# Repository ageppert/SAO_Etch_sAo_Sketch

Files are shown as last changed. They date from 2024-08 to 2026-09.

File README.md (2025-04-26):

# Etch sAo Sketch

The perfect pairing of an OLED Display, analog potentiometers, and a 3-axis accelerometer!

This is the primary repository for all things relevant to the Etch sAo Sketch.

Learn more about this project at: https://hackaday.io/project/197581-etch-sao-sketch

If you use the Arduino Demo code make sure it is configured for your hardware version (HWV) of the Etch sAo Sketch.

IMPORTANT ERRATA APPLIES TO ALL VERSIONS:

There is too much combined pull-up resistance with this board, the OLED board, the Hackaday Badge, and the Pico. This inhibits some I2C hardware implementations from working with the OLED display.

SOLUTION A: Firmware workaround is to use software I2C. See: https://github.com/ageppert/SAO_Etch_sAo_Sketch/pull/1

SOLUTION B: Hardware mods to remove interfering components. See: https://github.com/ageppert/SAO_Etch_sAo_Sketch/issues/8

-------------

# V1.3 - OLED VERSION - Hackaday Europe 2025 Elecrow version

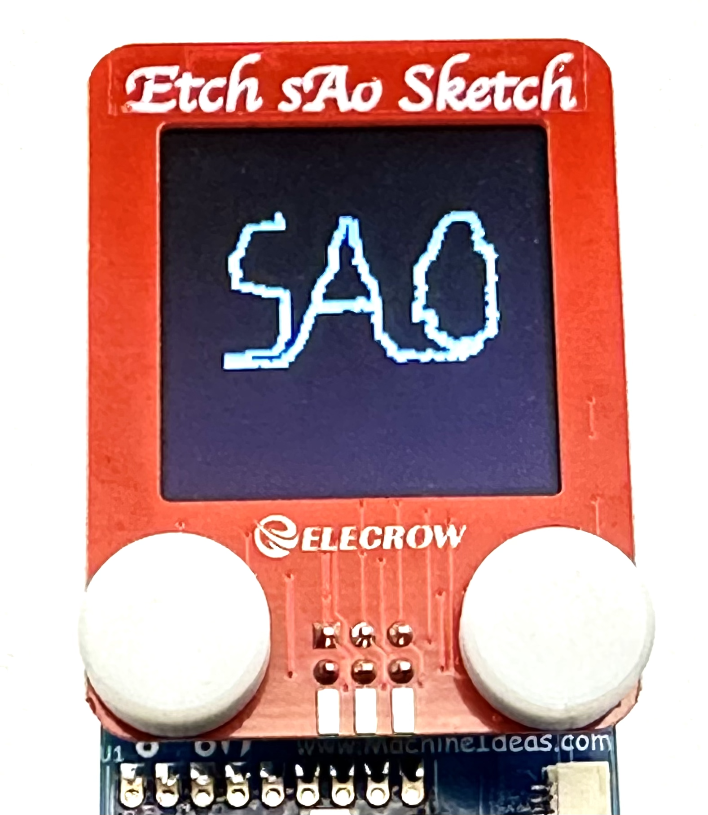
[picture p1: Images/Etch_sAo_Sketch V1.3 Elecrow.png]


This version was manufactured for Hackaday Europe 2025 by Elecrow and includes the Elecrow logo on the PCB below the screen. The files have been copied into this repository for easy reference, although it was in a more generic "SAO Sketch" repo for production. Hopefully you got a sticker from one of us to upgrade your SAO to "Etch sAo Sketch" when we were together in Berlin!

V1.3.1 FIXES: Removed I2C Pull-up Resistors R1/2 from the board.

-------------

# V1.2 - OLED VERSION - NOT BUILT

This version was an un-fabricated step in the development for Hackaday Europe 2025 with a separate repository located here: https://github.com/ageppert/SAO_Sketch. This version builds on V1.1 with some clean-up in the schematic and layout.

-------------

# V1.1 - OLED VERSION - Small batch to sell on Tindie

Refinements include:
1) Enable full range of the analog pots via the accelerometer's [reduced range] ADC inputs, with the option to still use analog signals on GPIO 1 and 2.
2) Use a taller male SAO header for easier connection to the main (red) PCBA.
3) Tweak alignment hole size/position for the alignment spheres and OLED position.

V1.1.1 FIXES: Removed I2C Pull-up Resistors R1/2 from the board.

Otherwise, it looks and functions just like V1.0.

-------------

# V1.0 - OLED VERSION - Shared at Hackaday Supercon.8 in 2024 and on Tindie

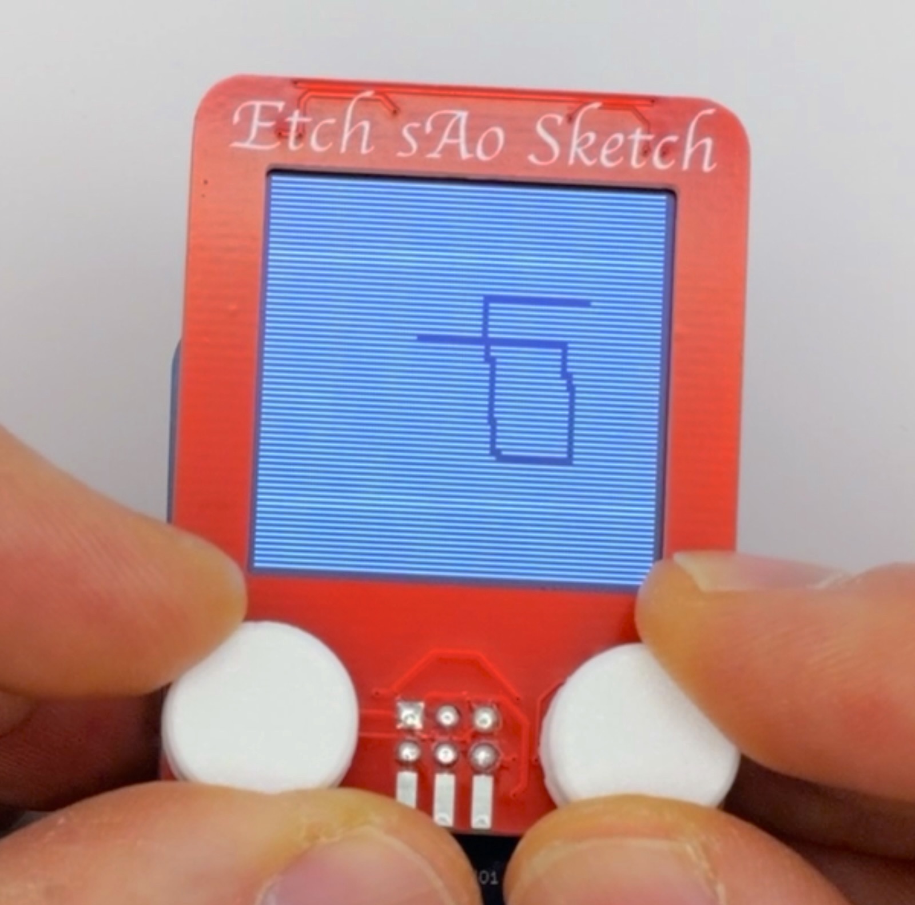
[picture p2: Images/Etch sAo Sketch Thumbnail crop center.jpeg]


This version was shared at Hackaday Supercon.8 2024. It is available for purchase here: https://www.tindie.com/products/36383/

V1.0.1 FIXES: Removed I2C Pull-up Resistors R30/31 from the board.

V1.0 ERRATA: The full travel of the analog pots is only available through [analog] GPIO1&2 of the SAO port, and this works best when connected to analog pins of an MCU. My SAO DEMO CONTROLLER is a good host to use the V1.0 Etch sAo Sketch with. A reduced range of travel is available through the accelerometer ADC inputs via I2C. The included SAO Header pins need to be pushed back into the header body 1 mm so they extend far enough to be connected to the red PCBA after the OLED PCBA is stacked on the bottom.

The SAO DEMO CONTROLLER is available for purchase here: https://www.tindie.com/products/36033/

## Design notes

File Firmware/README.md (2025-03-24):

# Etch_sAo_Sketch Firmware Examples

The Etch sAo Sketch requires a microcontroller with an I2C bus to run. This folder contains a few examples.

"Etch_sAo_Sketch_V1.0_RP2040_W_Arduino_Demo" is designed to work with the SAO Demo Controller, or any RP2040-based board. It provides the full drawing functionality for the V1 Etch sAo Sketch.

"Etch_sAo_Sketch_V1.1_RP2040_W_Arduino_Demo" is refined for the V1.1 Etch sAo Sketch which has resistors added in series with the potentiometers to allow full travel of the knobs to map to the full screen. It's a quality of life improvement.

"OLED_ssd1327_test" is Arduino sample code to activate the OLED screen.

"Supercon.8_Badge_Micropython" are the files needed to run the Etch sAo Sketch with the 2024 Supercon.8 and Hackaday Europe 2025 Badges using Micropython. Etch-sAo-Sketch must be plugged into the port marked "6" when the badge boots up. If used, the petal and touchwheel SAOs goes in "1", "2" or "3".

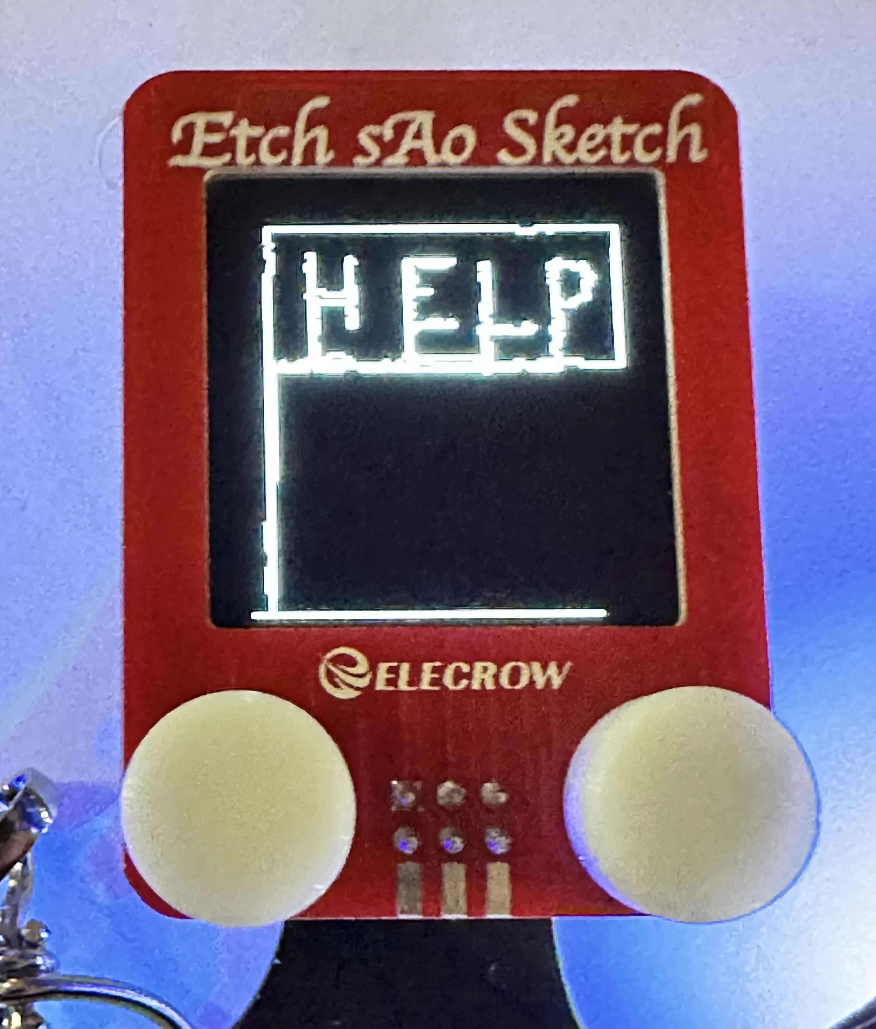
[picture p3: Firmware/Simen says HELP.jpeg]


Special thanks to these folks for the Micropython work!

https://github.com/AakaFosfor
Added filtering to analog signals.

https://github.com/ORelio
Bug fix, compatibility with Bendy SAO.

https://github.com/SimenZhor
Enabled full functionality and wrestling the SSD1327 setup config, live at Hackaday Europe!
Added calibration to the ends of the analog pot ranges.

https://github.com/jamisonderek
https://youtube.com/@MrDerekJamison
Supercon.8 2024 sample code provided by Derek Jamison.
"If the drawing area is smaller than the size of the screen, change the `calib_` values in `etch_sao_sketch.py` (`calib_left_zero_offset`, `calib_right_zero_offset`, and `calib_voltage_scaling`). The default values **work for me™**. Shaking the SAO will clear the screen, to turn off this functionality set `enable_shaking = False` in `main.py`."

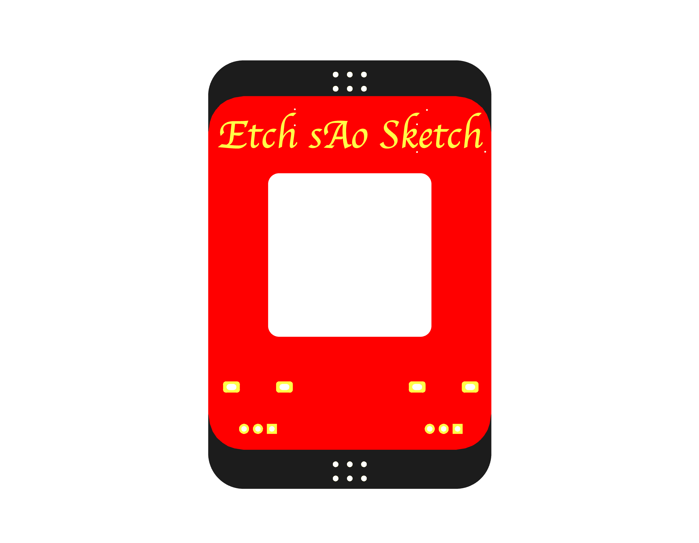
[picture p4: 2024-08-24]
Images/Etch sAo Sketch Concept 2024-08-24.png

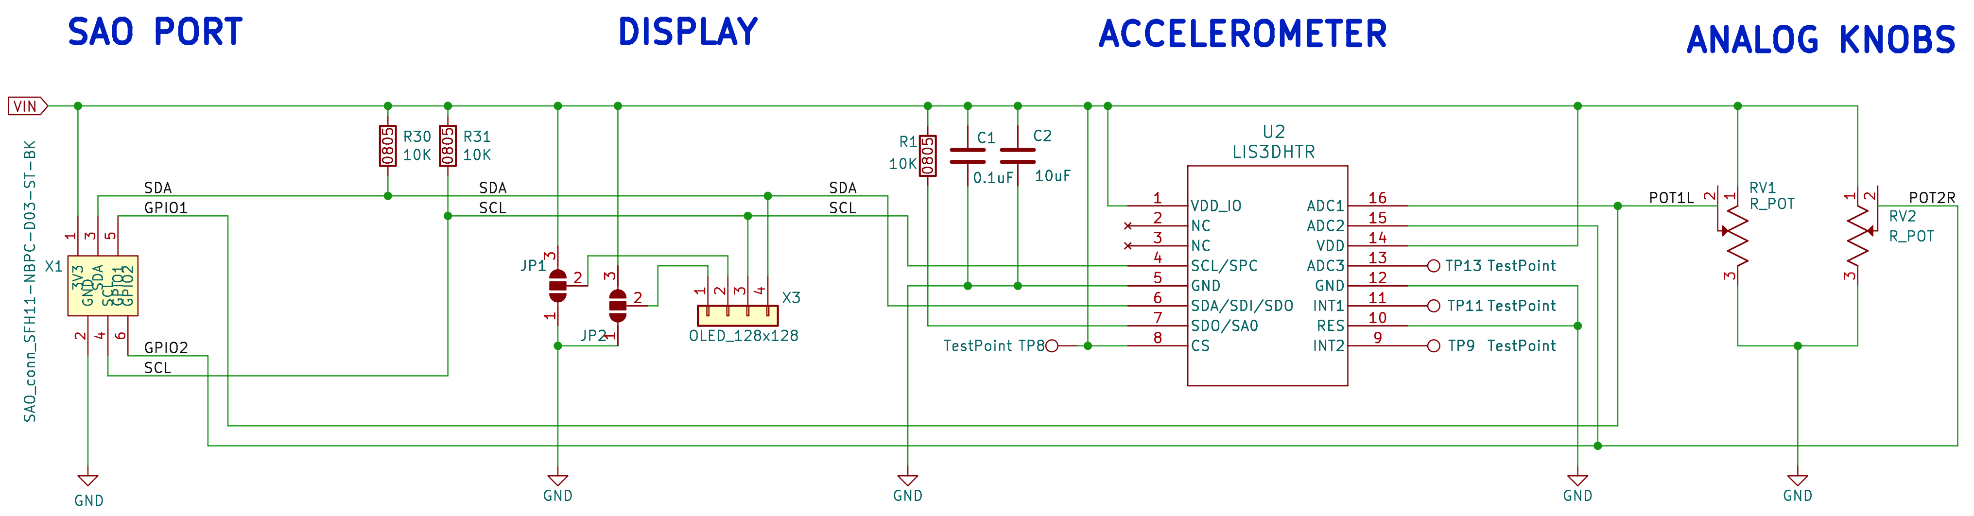
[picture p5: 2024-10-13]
Images/Etch_sAo_Sketch V1 Schematic snip.png

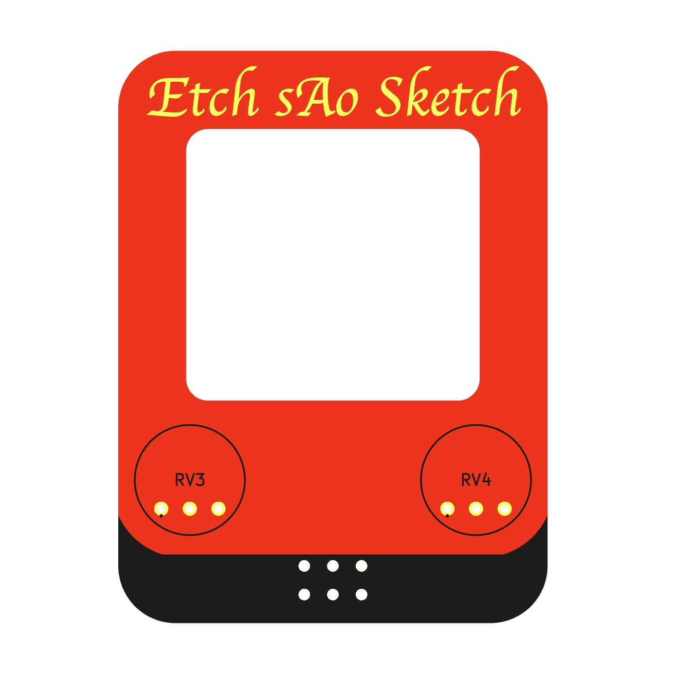
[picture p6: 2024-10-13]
Images/Etch sAo Sketch 40x50mm concept render.jpeg

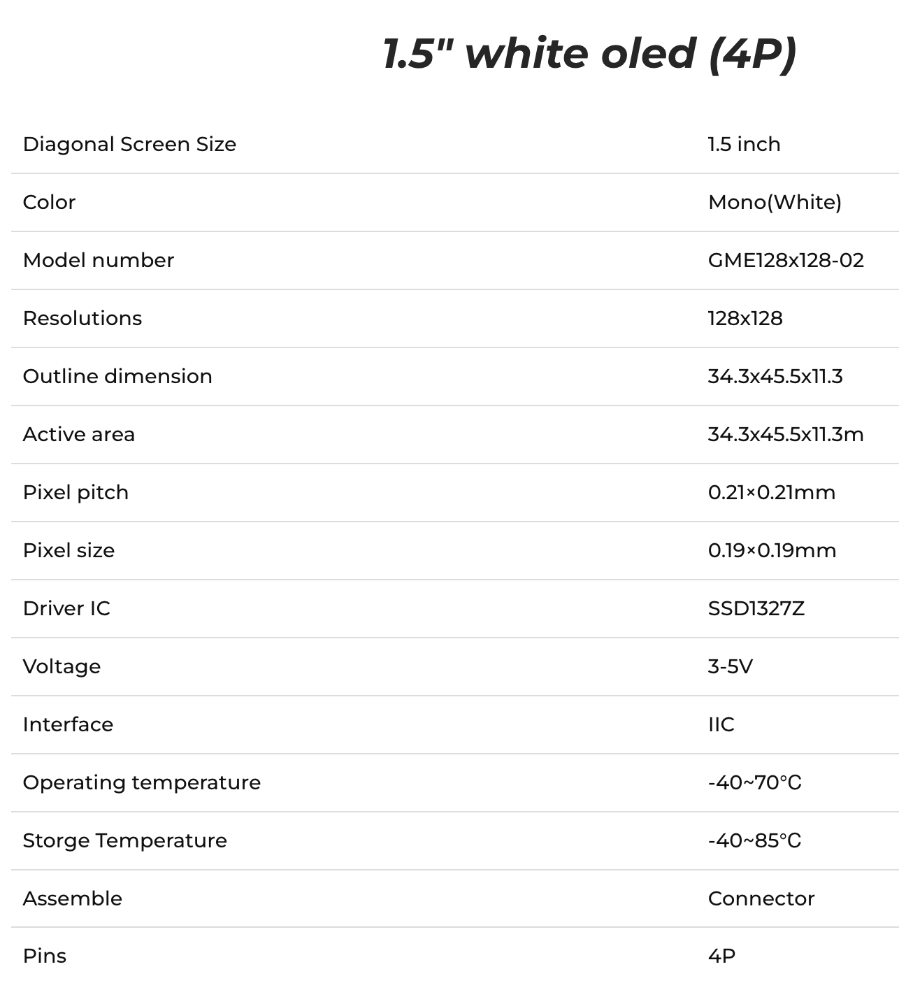
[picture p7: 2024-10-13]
Datasheets/OLED 1.5 128x128 specs use SSD1327 0x3c.png

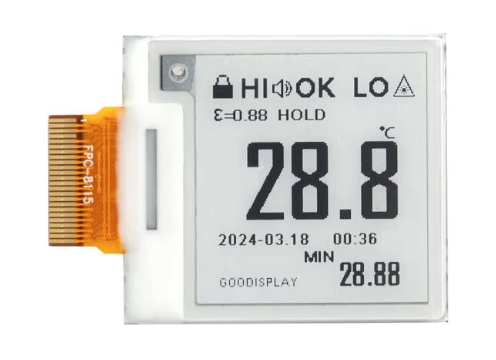
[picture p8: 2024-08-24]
Images/GooDisplay 1.22.png

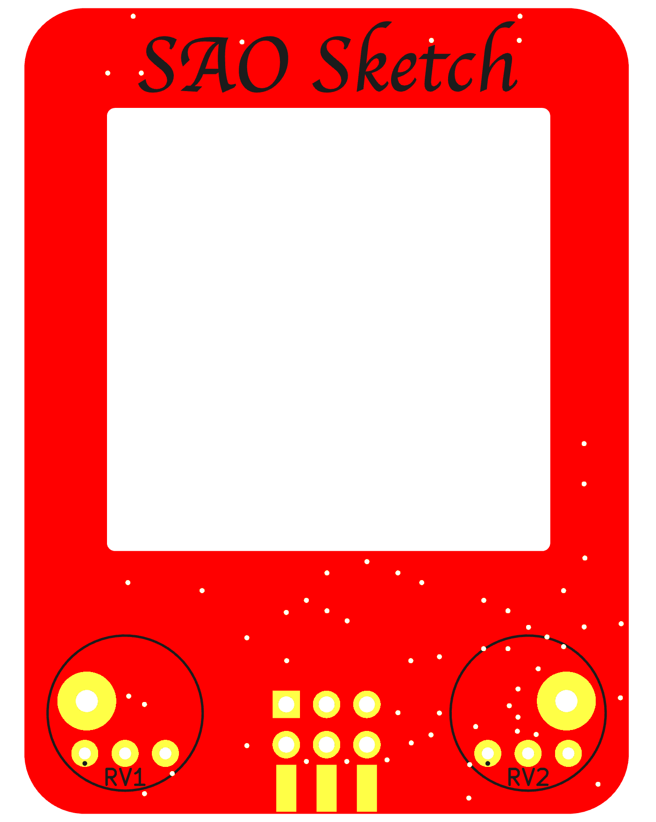
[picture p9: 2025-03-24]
Images/SAO Sketch Render Front V1.2.png

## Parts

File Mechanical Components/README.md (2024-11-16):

# MECHANICAL COMPONENTS

The knob cap used with this project. Printed with Prusa i3 MK3, white PETG, 100%, 0.10 mm layers.

SOURCE CAD: https://cad.onshape.com/documents/c3882db33ae2dd1c523040a7/w/bc79ec441b0d4d8fc9cb55e7/e/deefde449b3372b7c97927bc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

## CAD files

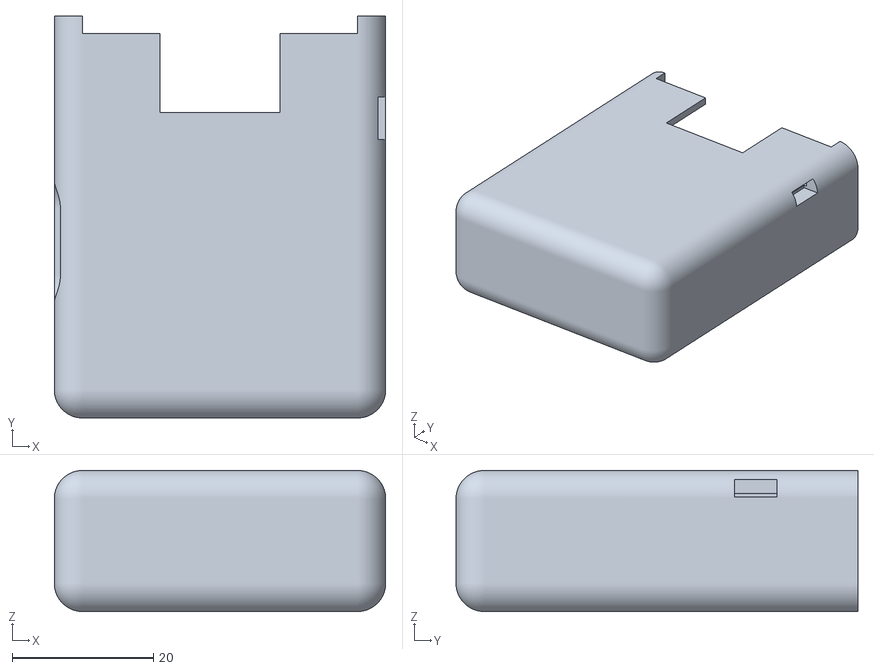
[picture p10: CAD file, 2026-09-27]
Mechanical Components/Etch sAo Sketch Case Main V1.stl
47.0 x 57.0 x 20.0

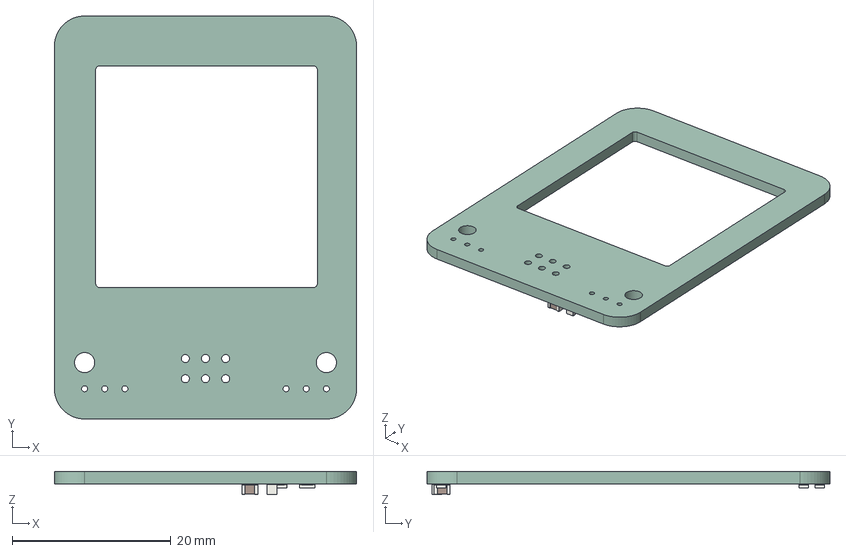
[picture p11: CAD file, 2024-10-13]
Images/Etch_sAo_Sketch.step
38.1 x 50.8 x 2.90 mm
R_0805_2012Metric x 3
C_0805_2012Metric x 2
Etch_sAo_Sketch_PCB

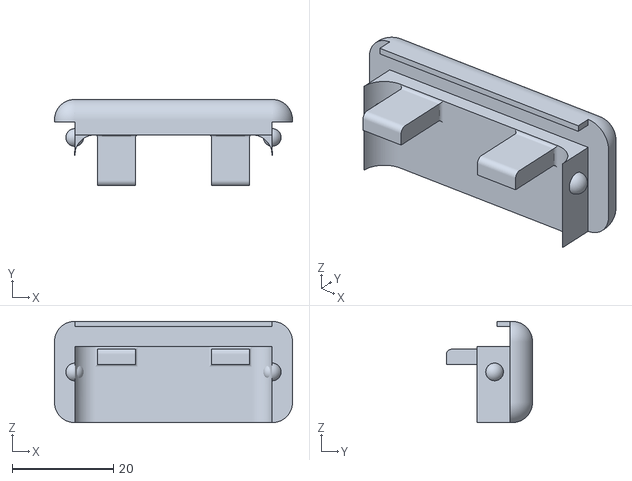
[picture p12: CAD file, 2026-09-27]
Mechanical Components/Etch sAo Sketch Case Plug V1.stl
47.0 x 17.0 x 20.0

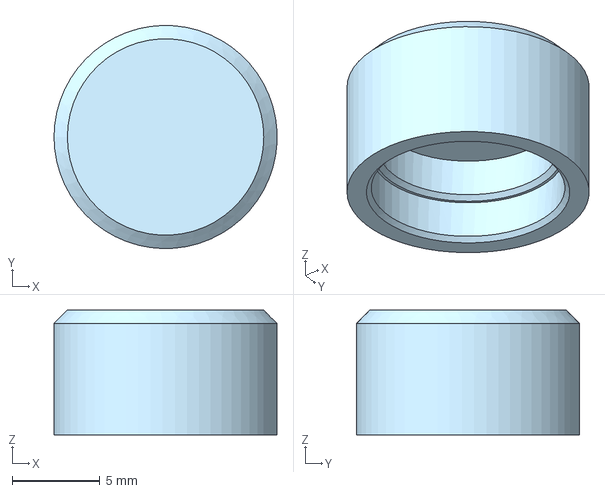
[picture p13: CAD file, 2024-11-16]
Mechanical Components/Etch sAo Sketch Pot Cap V1.step
12.7 x 12.7 x 7.11 mm

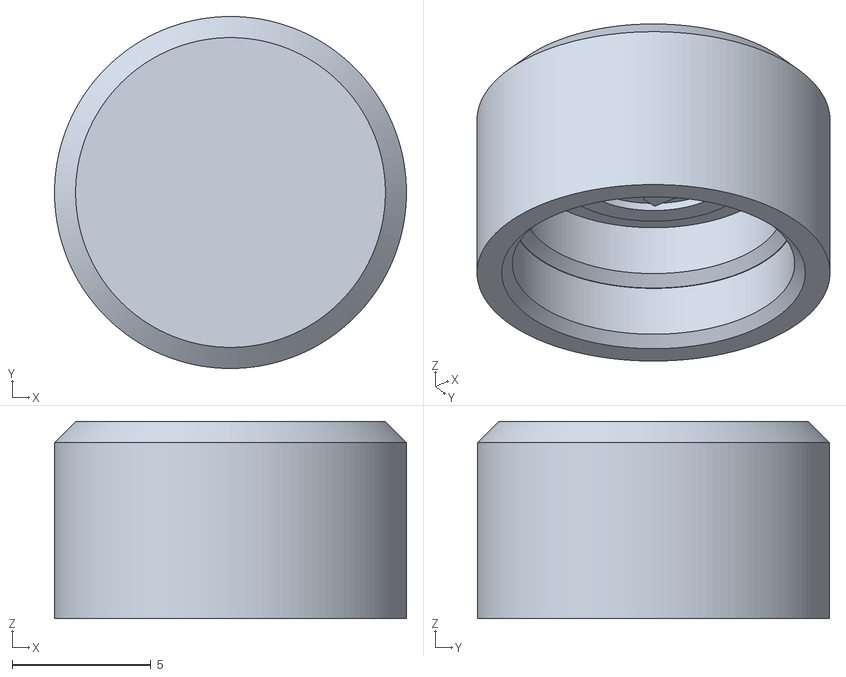
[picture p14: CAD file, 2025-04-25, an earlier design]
Mechanical Components/Etch sAo Sketch Pot Cap V2.stl
12.7 x 12.7 x 7.11

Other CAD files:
Mechanical Components/Etch sAo Sketch Pot Cap V4.stl
Mechanical Components/Etch sAo Sketch Pot Cap V1.iges
Mechanical Components/Etch sAo Sketch Pot Cap V1.sldprt
Mechanical Components/Etch sAo Sketch Pot Cap V1.x_t

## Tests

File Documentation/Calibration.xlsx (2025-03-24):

Badge with multiple SAOs and USB Power |  | Badge, no SAOs, USB Power | Assumed calibration limits
Left knob, left | 26400 | 27000
Left knob, right | 64000 | 64300
Right knob, left | 26400 | 27000
Right knob, right | 64000 | 64300
If left and right knobs are turned full right at start up (> 60000)

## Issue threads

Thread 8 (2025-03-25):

Pull-up resistors

AakaFosfor, 2025-03-25:
Beside SW updates (already merged in this repo), also HW updates were needed to get the version 1.3 up and running. When combined with the Hackaday Europe 2025 badge (e.g., in the port 6), following pulls and other components are on the I2C bus (SCL/SDA):

- badge itself: pull-ups R1/R2 (3k3)
- Etch sAo Sketch red board: pull-ups R1/R2 (4k7)
- GME128128-02 v3.1 blue board
  - pull-ups R2/R3 (10k)
  - series resistors R7/R8 (1k)
  - clamp-down zener diods (ZD1/ZD2)

There are no other pull-ups on the Raspeberry Pi Pico W SoM; not sure if there are any (optional?) pulls inside of the RP2350A0A2 chip.

The pulls which are there give some 1k6 together, which migth be too low. And zener diods seems to not allow the ACK from the display driver to sink enough (if I remember some scope measurements shared after the event). This might be the reason why the HW I2C cannot communicate with this chip and the software one needs to be used.

Modifications proposed in https://forums.raspberrypi.com/viewtopic.php?t=352484 (removing zener diods and shorting series resistors) together with removing pulls on the GME board, the extended I2C timeout and the transaction segmentation (see #7) allows the HW I2C usage again.

So, creating this issue to track this and possibly improve it in a next version (if planned). In general, I would suggest to avoid any pull-ups on the I2C bus on slave boards. Those should be added on the master/platform side just once for the whole bus.

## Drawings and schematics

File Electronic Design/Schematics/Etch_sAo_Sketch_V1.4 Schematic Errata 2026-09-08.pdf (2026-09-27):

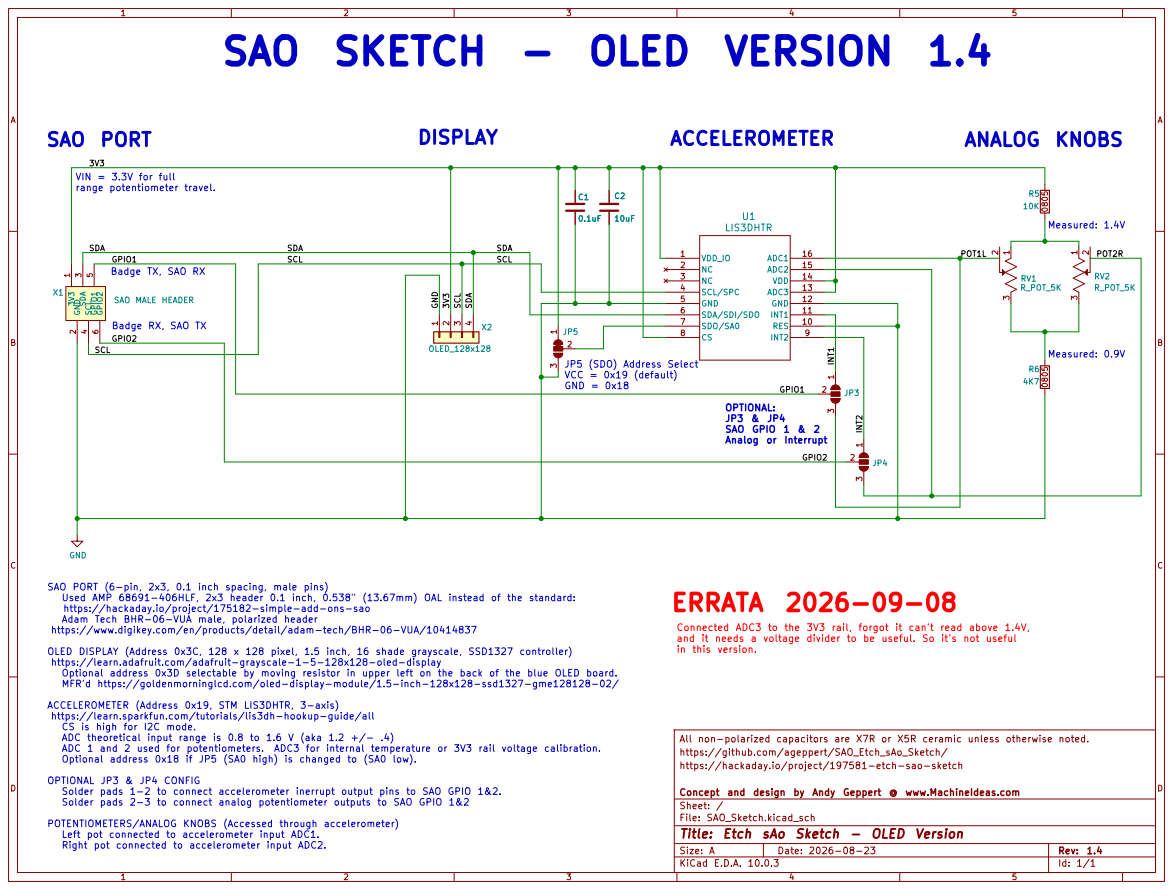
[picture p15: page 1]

SAO SKETCH - OLED VERSION 1.4

SCL SDA SCL SDA 3V3
range potentiometer travel.

Badge TX, SAO RX

SDA/SDI/SDO 6
SDO/SA0 7 CS 8

Badge RX, SAO TX

SAO PORT (6-pin, 2x3, 0.1 inch spacing, male pins)
Used AMP 68691-406HLF, 2x3 header 0.1 inch, 0.538" (13.67mm) OAL instead of the standard:
https://hackaday.io/project/175182-simple-add-ons-sao
Adam Tech BHR-06-VUA male, polarized header
https://www.digikey.com/en/products/detail/adam-tech/BHR-06-VUA/10414837

Connected ADC3 to the 3V3 rail, forgot it can't read above 1.4V,
and it needs a voltage divider to be useful. So it's not useful
in this version.

OLED DISPLAY (Address 0x3C, 128 x 128 pixel, 1.5 inch, 16 shade grayscale, SSD1327 controller)
https://learn.adafruit.com/adafruit-grayscale-1-5-128x128-oled-display
Optional address 0x3D selectable by moving resistor in upper left on the back of the blue OLED board.
MFR'd https://goldenmorninglcd.com/oled-display-module/1.5-inch-128x128-ssd1327-gme128128-02/

ACCELEROMETER (Address 0x19, STM LIS3DHTR, 3-axis)
https://learn.sparkfun.com/tutorials/lis3dh-hookup-guide/all
CS is high for I2C mode.
ADC theoretical input range is 0.8 to 1.6 V (aka 1.2 +/- .4)
ADC 1 and 2 used for potentiometers. ADC3 for internal temperature or 3V3 rail voltage calibration.
Optional address 0x18 if JP5 (SA0 high) is changed to (SA0 low).

All non-polarized capacitors are X7R or X5R ceramic unless otherwise noted.
https://github.com/ageppert/SAO_Etch_sAo_Sketch/
https://hackaday.io/project/197581-etch-sao-sketch

OPTIONAL JP3 & JP4 CONFIG
Solder pads 1-2 to connect accelerometer inerrupt output pins to SAO GPIO 1&2.
Solder pads 2-3 to connect analog potentiometer outputs to SAO GPIO 1&2

Concept and design by Andy Geppert @ www.MachineIdeas.com
Sheet: /
File: SAO_Sketch.kicad_sch
Title: Etch sAo Sketch - OLED Version

POTENTIOMETERS/ANALOG KNOBS (Accessed through accelerometer)
Left pot connected to accelerometer input ADC1.
Right pot connected to accelerometer input ADC2.

Size: A | Rev: 1.4
KiCad E.D.A. 10.0.3 | Id: 1/1

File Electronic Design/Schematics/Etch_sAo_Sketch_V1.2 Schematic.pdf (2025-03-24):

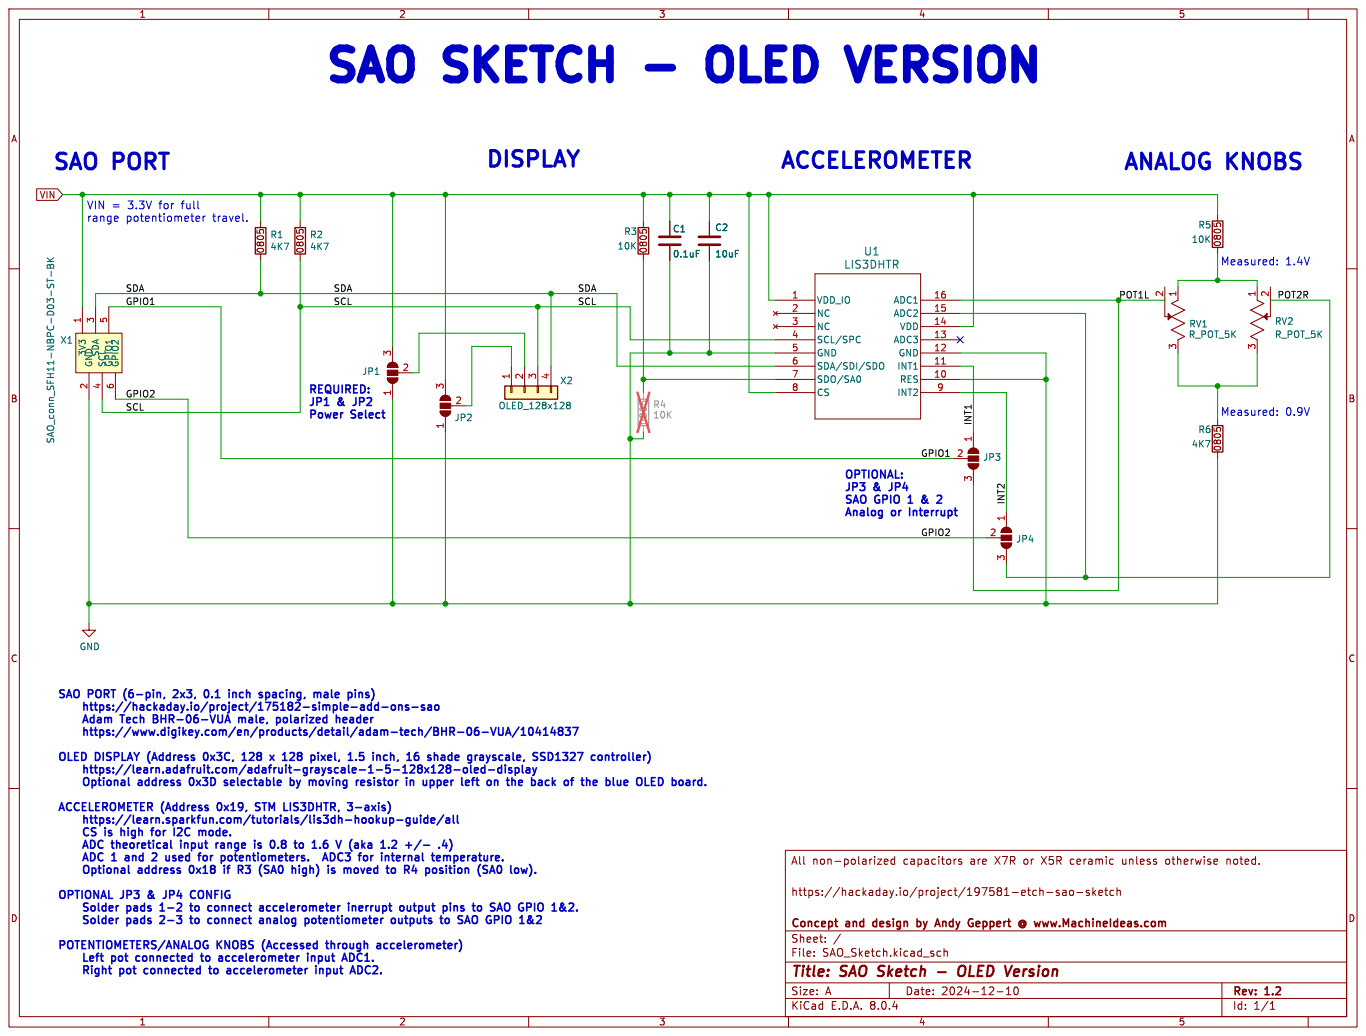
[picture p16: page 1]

REQUIRED: JP1 & JP2 Power Select SAO PORT

https://learn.adafruit.com/adafruit-grayscale-1-5-128x128-oled-display

Optional address 0x18 if R3 (SA0 high) is moved to R4 position (SA0 low). OPTIONAL JP3 & JP4 CONFIG

Id: 1/1 Title: SAO Sketch - OLED Version

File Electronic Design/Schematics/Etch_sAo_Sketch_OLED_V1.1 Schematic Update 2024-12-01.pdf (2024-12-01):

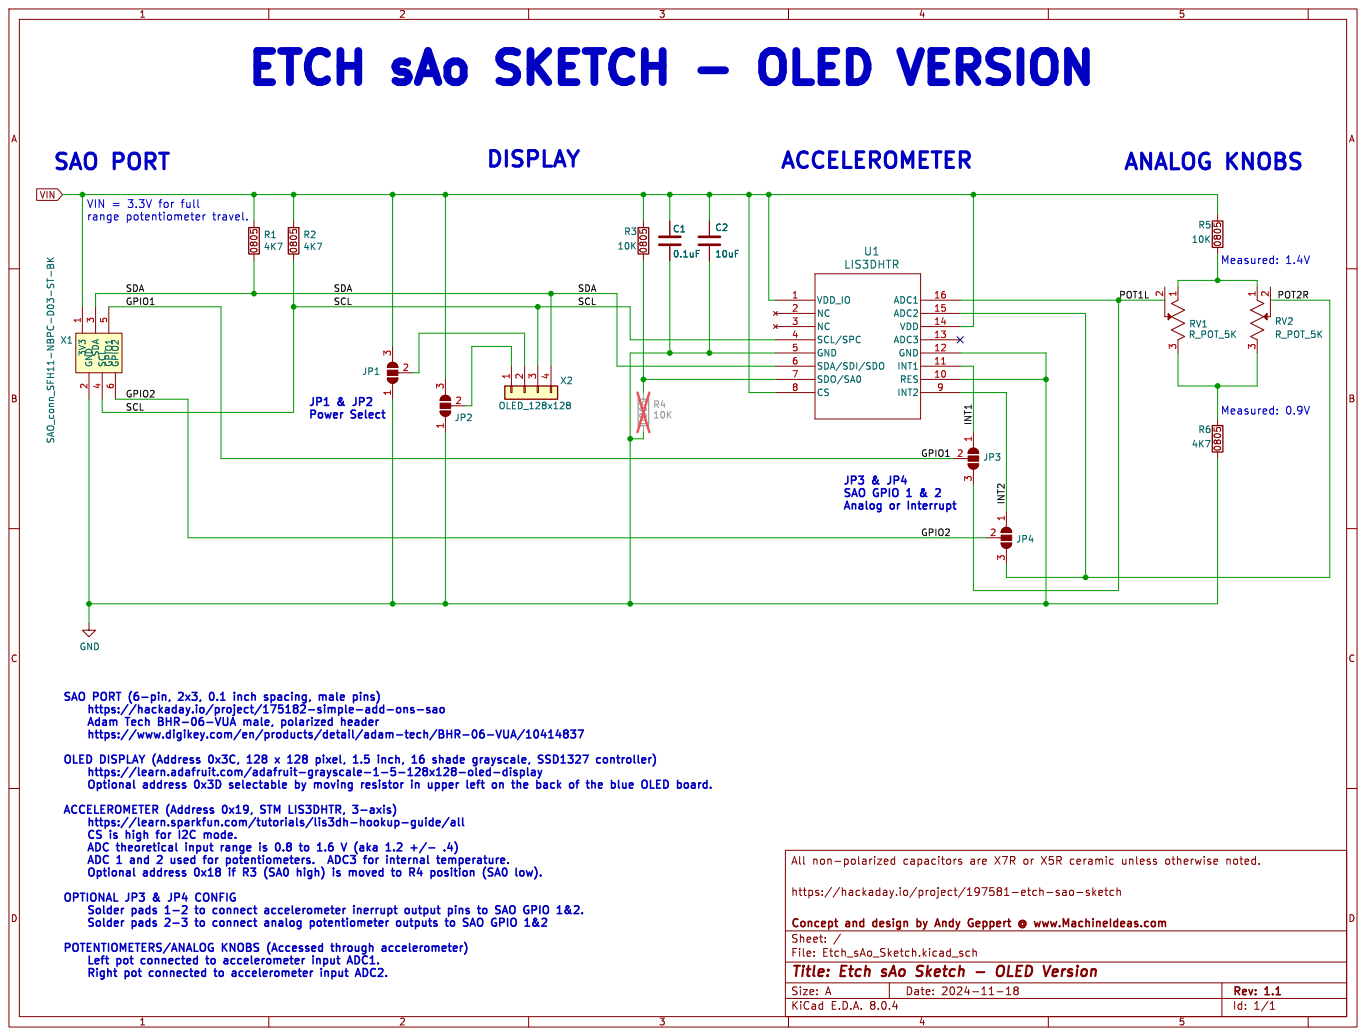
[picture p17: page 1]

JP3 & JP4 SAO GPIO 1 & 2 Analog or Interrupt

https://learn.adafruit.com/adafruit-grayscale-1-5-128x128-oled-display

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

Id: 1/1 Title: Etch sAo Sketch - OLED Version

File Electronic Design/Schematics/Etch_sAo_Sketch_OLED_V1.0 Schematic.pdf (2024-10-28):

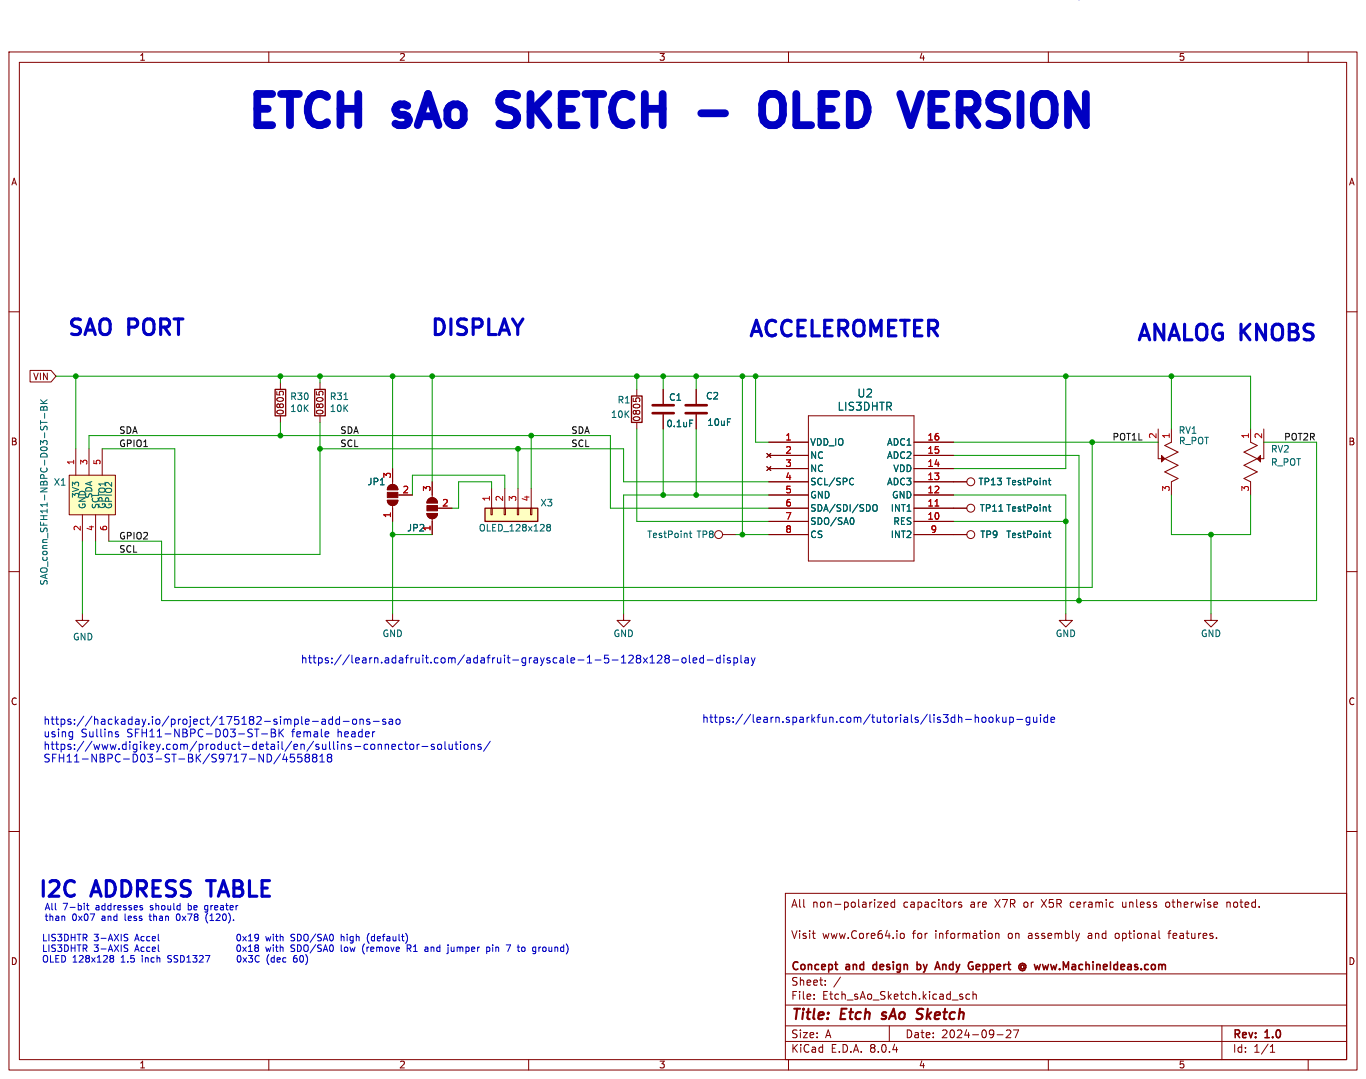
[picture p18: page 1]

https://learn.adafruit.com/adafruit-grayscale-1-5-128x128-oled-display

https://hackaday.io/project/175182-simple-add-ons-sao

https://learn.sparkfun.com/tutorials/lis3dh-hookup-guide

Id: 1/1 Title: Etch sAo Sketch

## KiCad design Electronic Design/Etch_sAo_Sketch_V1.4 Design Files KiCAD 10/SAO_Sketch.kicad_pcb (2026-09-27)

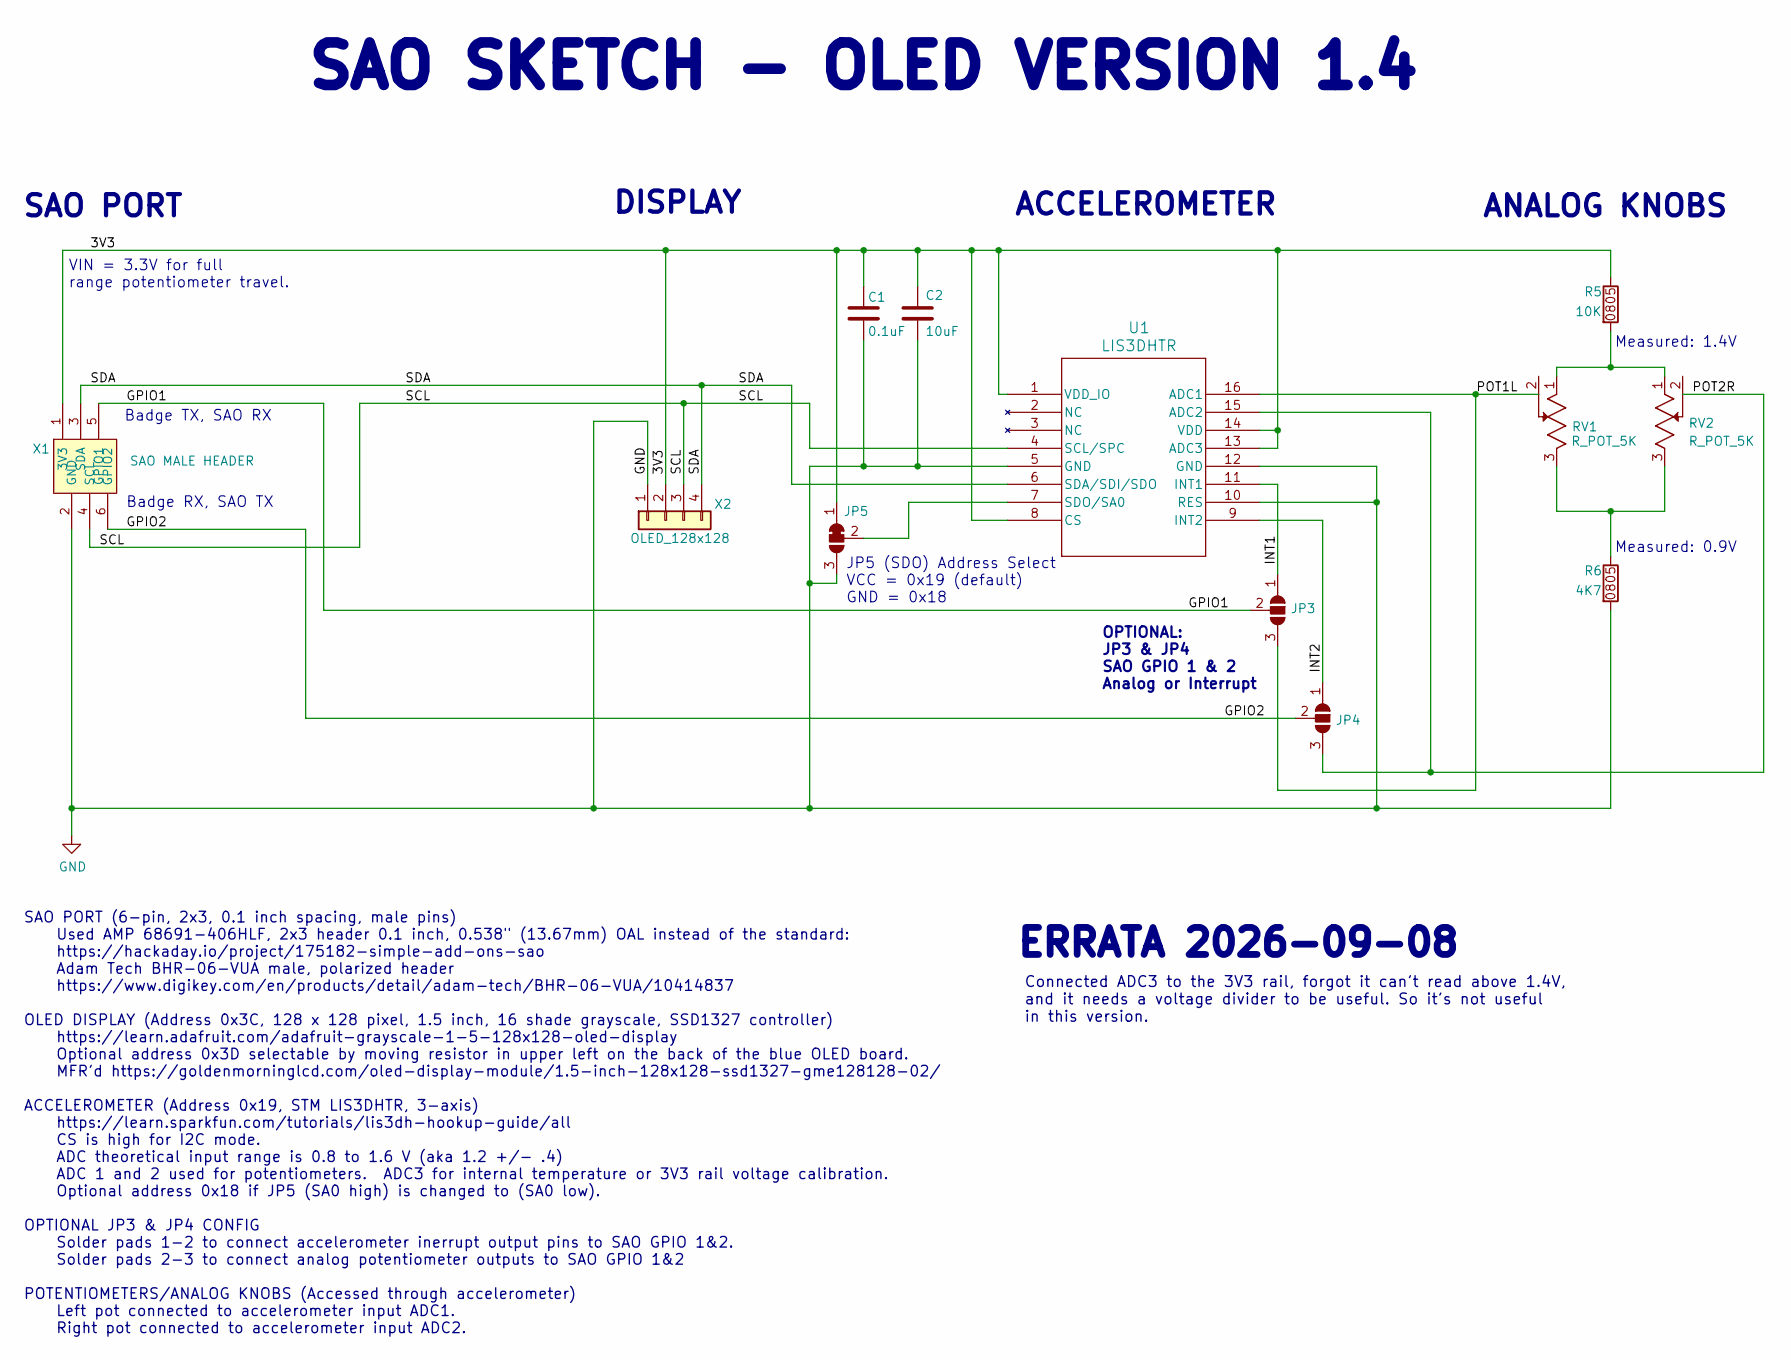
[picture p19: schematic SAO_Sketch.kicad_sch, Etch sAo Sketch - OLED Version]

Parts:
C1: 0.1uF; C_0805_2012Metric; LCSC C28233
C2: 10uF; C_0805_2012Metric; LCSC C15850
JP3, JP4: SolderJumper_3_Open; SolderJumper-3_P1.3mm_Open_RoundedPad1.0x1.5mm_NumberLabels
JP5: SolderJumper_3_Bridged12; SolderJumper-3_P1.3mm_Bridged12_RoundedPad1.0x1.5mm_NumberL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
R5: 10K; R_0805_2012Metric; LCSC C17414
R6: 4K7; R_0805_2012Metric; LCSC C17673
RV1, RV2: R_POT_5K; POT_RES3_91A_TTE; Manufacturer_Part_Number 91AR5KLF; Digi-Key_PN 987-1171-ND
U1: LIS3DHTR; LGA-16_3x3x1mm_STM; Manufacturer_Part_Number LIS3DHTR; Digi-Key_PN 497-10613-2-ND
X1: SAO MALE HEADER; Badgelife-SAOv169-BADGE-2x3-PINS-SHROUD-no-front-text; MPN 68691-406HLF; Digi-Key_PN 609-68691-406HLF-ND
X2: OLED_128x128; OLED_1.50_128x128

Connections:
/3V3: C1.1, C2.1, JP5.1 (A), R5.1, U1.1 (VDD_IO), U1.8 (CS), U1.13 (ADC3), U1.14 (VDD), X1.1 (3V3), X2.2
/GPIO1: JP3.2 (C), X1.5 (GPIO1)
/GPIO2: JP4.2 (C), X1.6 (GPIO2)
/INT1: JP3.1 (A), U1.11 (INT1)
/INT2: JP4.1 (A), U1.9 (INT2)
/POT1L: JP3.3 (B), RV1.2, U1.16 (ADC1)
/POT2R: JP4.3 (B), RV2.2, U1.15 (ADC2)
/SCL: U1.4 (SCL/SPC), X1.4 (SCL), X2.3
/SDA: U1.6 (SDA/SDI/SDO), X1.3 (SDA), X2.4
GND: C1.2, C2.2, JP5.3 (B), R6.2, U1.5 (GND), U1.10 (RES), U1.12 (GND), X1.2 (GND), X2.1
unnamed: JP5.2 (C), U1.7 (SDO/SA0)
unnamed: R5.2, RV1.1, RV2.1
unnamed: R6.1, RV1.3, RV2.3

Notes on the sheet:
Badge TX, SAO RX
SAO PORT (6-pin, 2x3, 0.1 inch spacing, male pins) Used AMP 68691-406HLF, 2x3 header 0.1 inch, 0.538" (13.67mm) OAL instead of the standard: https://hackaday.io/project/175182-simple-add-ons-sao Adam Tech BHR-06-VUA male, polarized header https://www.digikey.com/en/products/detail/adam-tech/BHR-06-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
Measured: 1.4V
DISPLAY
ANALOG KNOBS
SAO SKETCH - OLED VERSION 1.4
Measured: 0.9V
VIN = 3.3V for full range potentiometer travel.
JP5 (SDO) Address Select VCC = 0x19 (default) GND = 0x18
OPTIONAL: JP3 & JP4 SAO GPIO 1 & 2 Analog or Interrupt
Badge RX, SAO TX
Connected ADC3 to the 3V3 rail, forgot it can't read above 1.4V, and it needs a voltage divider to be useful. So it's not useful in this version.
ACCELEROMETER
SAO PORT
ERRATA 2026-09-08

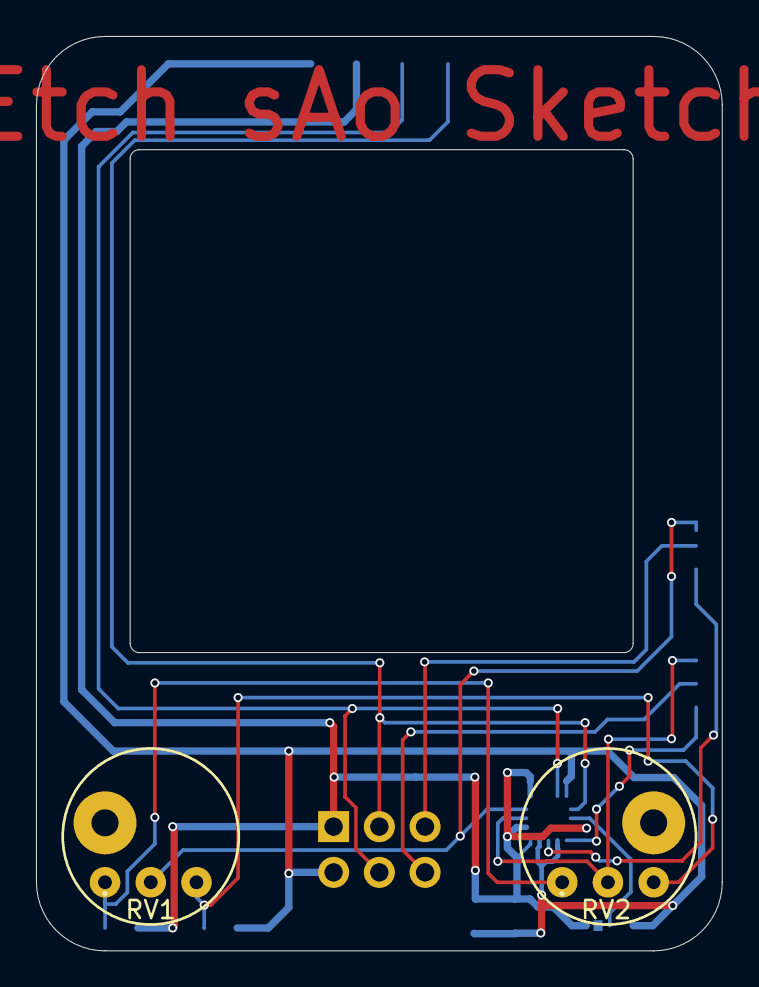
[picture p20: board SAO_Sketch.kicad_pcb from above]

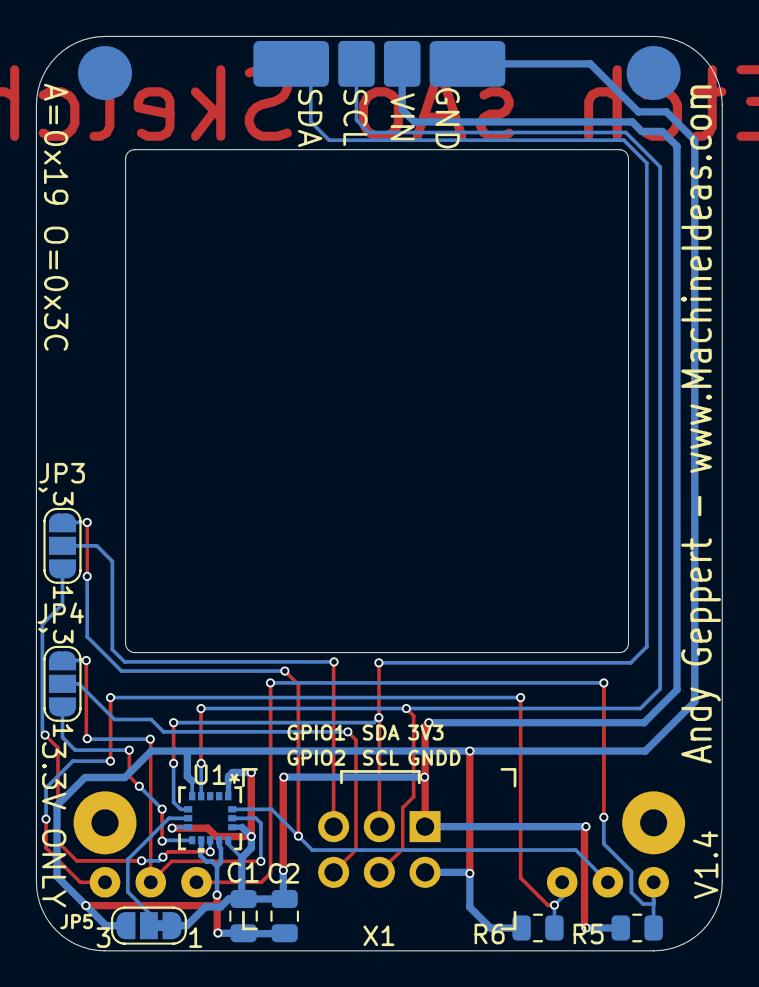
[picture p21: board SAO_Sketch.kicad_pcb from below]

Board: 2 copper layers, 38.1 x 50.8 mm, 12 parts (9 on the bottom side), 13 nets.

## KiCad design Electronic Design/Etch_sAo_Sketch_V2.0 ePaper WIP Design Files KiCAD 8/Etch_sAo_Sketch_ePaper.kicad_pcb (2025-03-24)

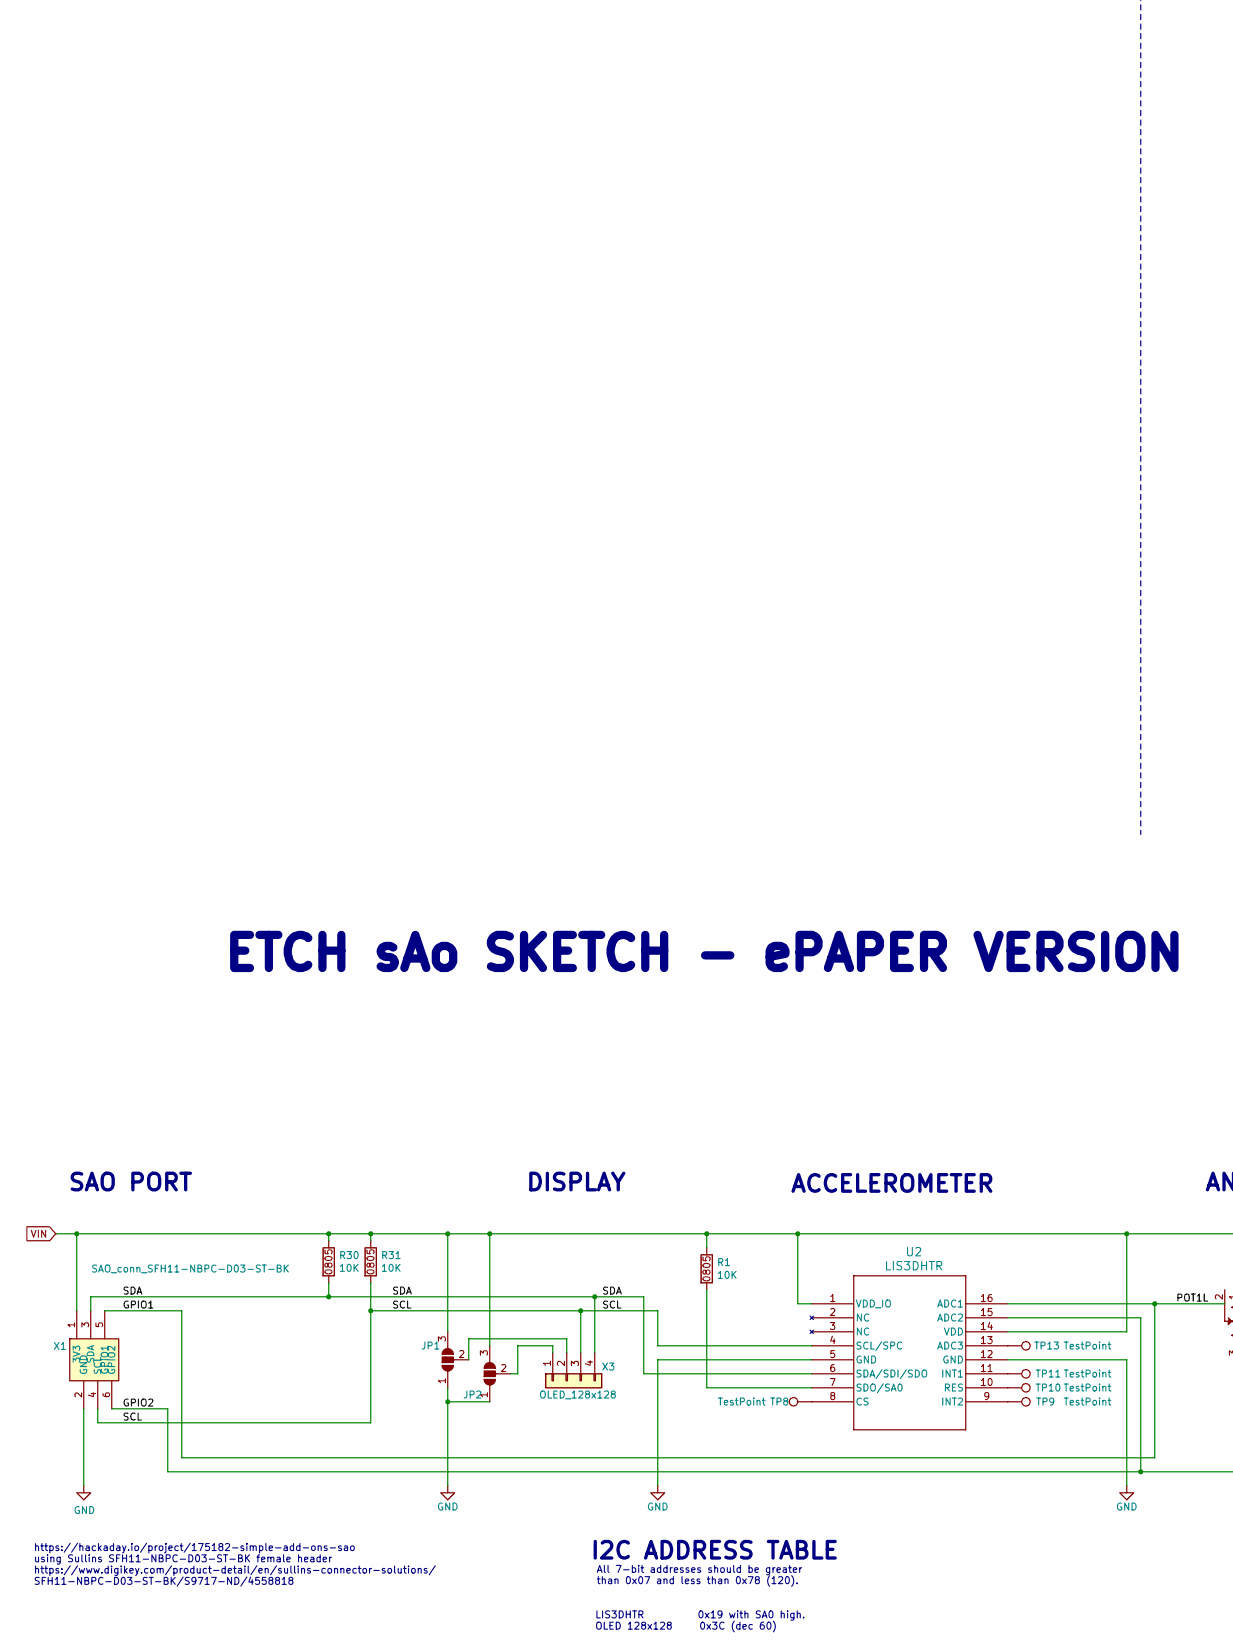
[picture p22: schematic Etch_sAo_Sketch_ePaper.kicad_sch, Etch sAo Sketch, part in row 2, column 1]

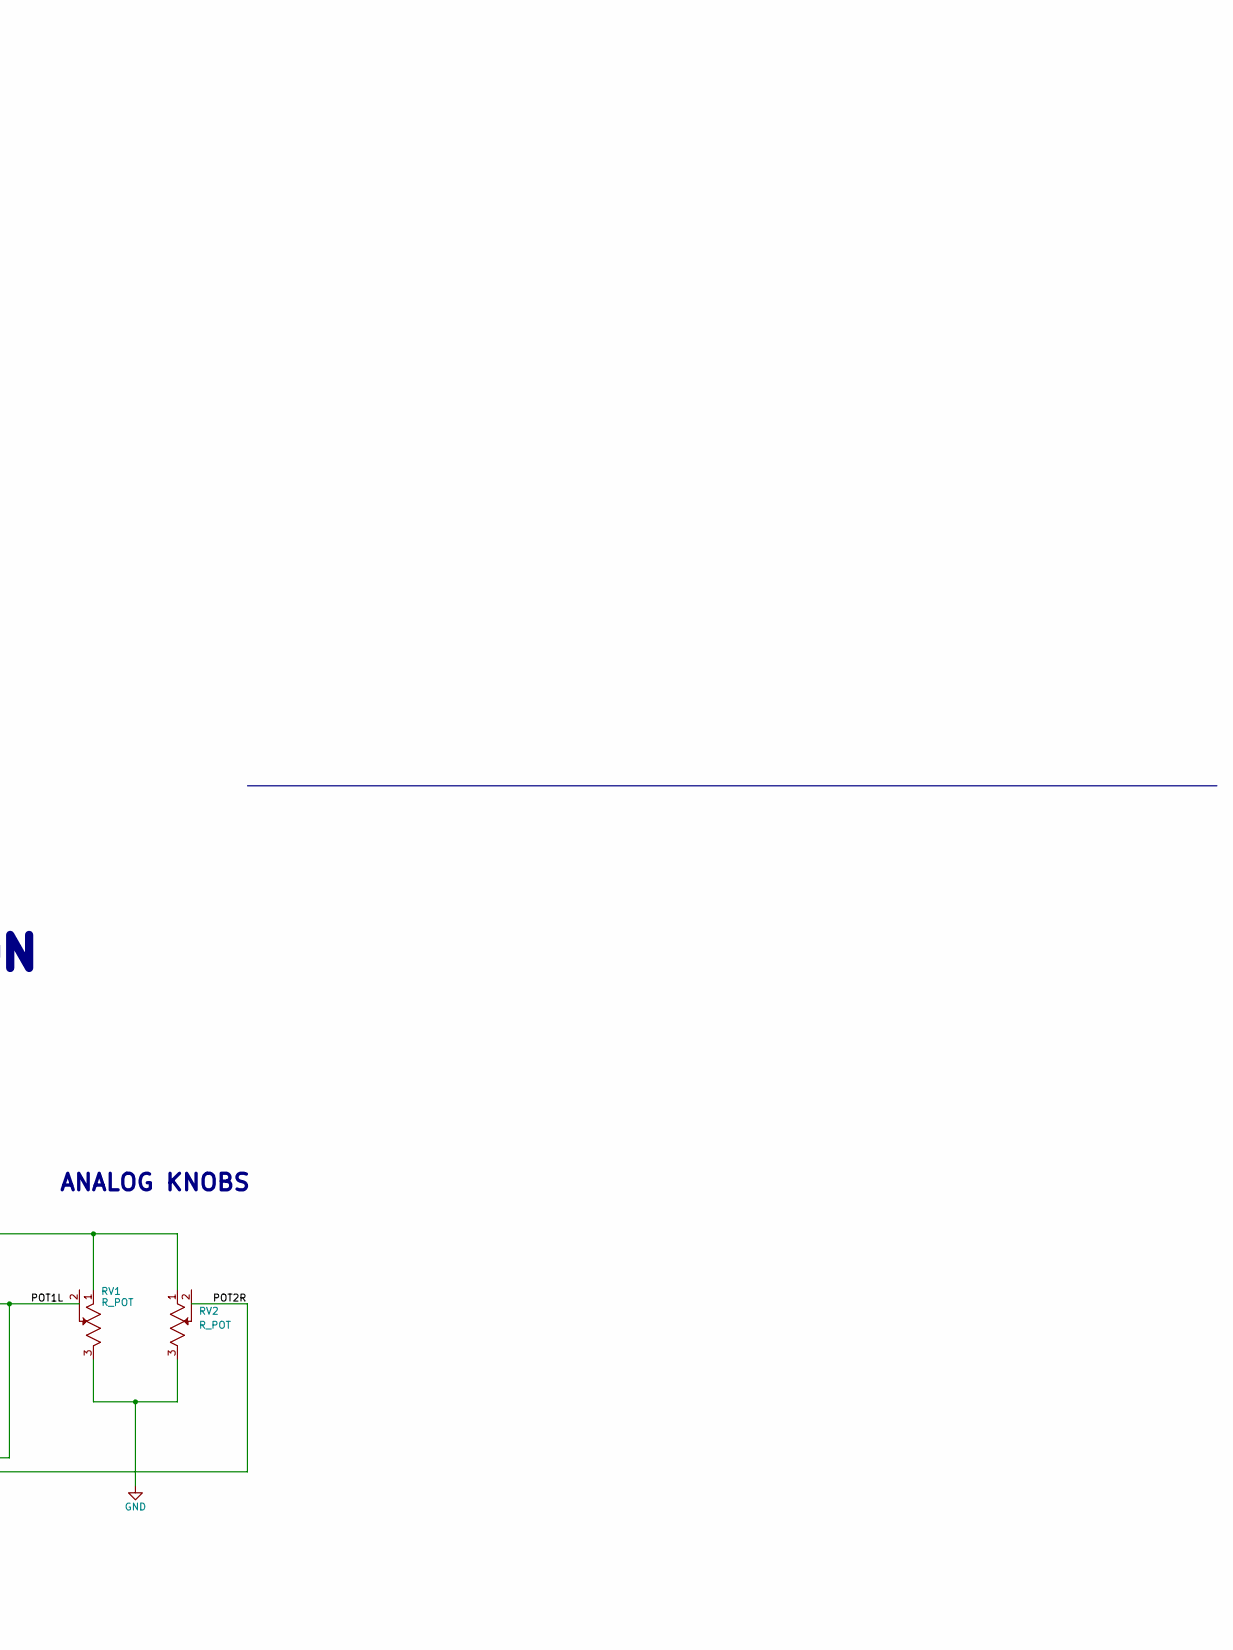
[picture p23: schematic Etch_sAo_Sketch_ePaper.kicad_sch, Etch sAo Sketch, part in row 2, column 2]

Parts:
JP1, JP2: SolderJumper_3_Open; SolderJumper-3_P1.3mm_Open_RoundedPad1.0x1.5mm_NumberLabels
R1, R30, R31: 10K; R_0805_2012Metric; LCSC C17414
RV1, RV2: R_POT; POT_RES3_91A_TTE
TP8, TP9, TP10, TP11, TP13: TestPoint; TestPoint_Pad_1.0x1.0mm
U2: LIS3DHTR; LGA-16_3x3x1mm_STM; Manufacturer_Part_Number LIS3DHTR; Digi-Key_PN 497-10613-2-ND
X1: SAO_conn_SFH11-NBPC-D03-ST-BK; Badgelife-SAOv169-BADGE-2x3-Edge-Connect-no-front-text; MPN SFH11-NBPC-D03-ST-BK
X3: OLED_128x128; OLED_1.50_128x128

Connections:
/GPIO1: RV1.2, U2.16 (ADC1), X1.5 (GPIO1)
/GPIO2: RV2.2, U2.15 (ADC2), X1.6 (GPIO2)
/SCL: R31.2, U2.4 (SCL/SPC), X1.4 (SCL), X3.3
/SDA: R30.2, U2.6 (SDA/SDI/SDO), X1.3 (SDA), X3.4
GND: JP1.1 (A), JP2.1 (A), RV1.3, RV2.3, U2.5 (GND), U2.12 (GND), X1.2 (GND)
unnamed: JP1.2 (C), X3.2
unnamed: JP2.2 (C), X3.1
unnamed: TP13.1, U2.13 (ADC3)
unnamed: TP8.1, U2.8 (CS)
unnamed: TP11.1, U2.11 (INT1)
unnamed: TP9.1, U2.9 (INT2)
unnamed: TP10.1, U2.10 (RES)
unnamed: R1.2, U2.7 (SDO/SA0)
VIN: JP1.3 (B), JP2.3 (B), R1.1, R30.1, R31.1, RV1.1, RV2.1, U2.1 (VDD_IO), U2.14 (VDD), X1.1 (3V3)

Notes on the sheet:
https://hackaday.io/project/175182-simple-add-ons-sao using Sullins SFH11-NBPC-D03-ST-BK female header https://www.digikey.com/product-detail/en/sullins-connector-solutions/ SFH11-NBPC-D03-ST-BK/S9717-ND/4558818
LIS3DHTR 0x19 with SA0 high. OLED 128x128 0x3C (dec 60)
DISPLAY
ANALOG KNOBS
ETCH sAo SKETCH - ePAPER VERSION
I2C ADDRESS TABLE
ACCELEROMETER
All 7-bit addresses should be greater than 0x07 and less than 0x78 (120).
SAO PORT

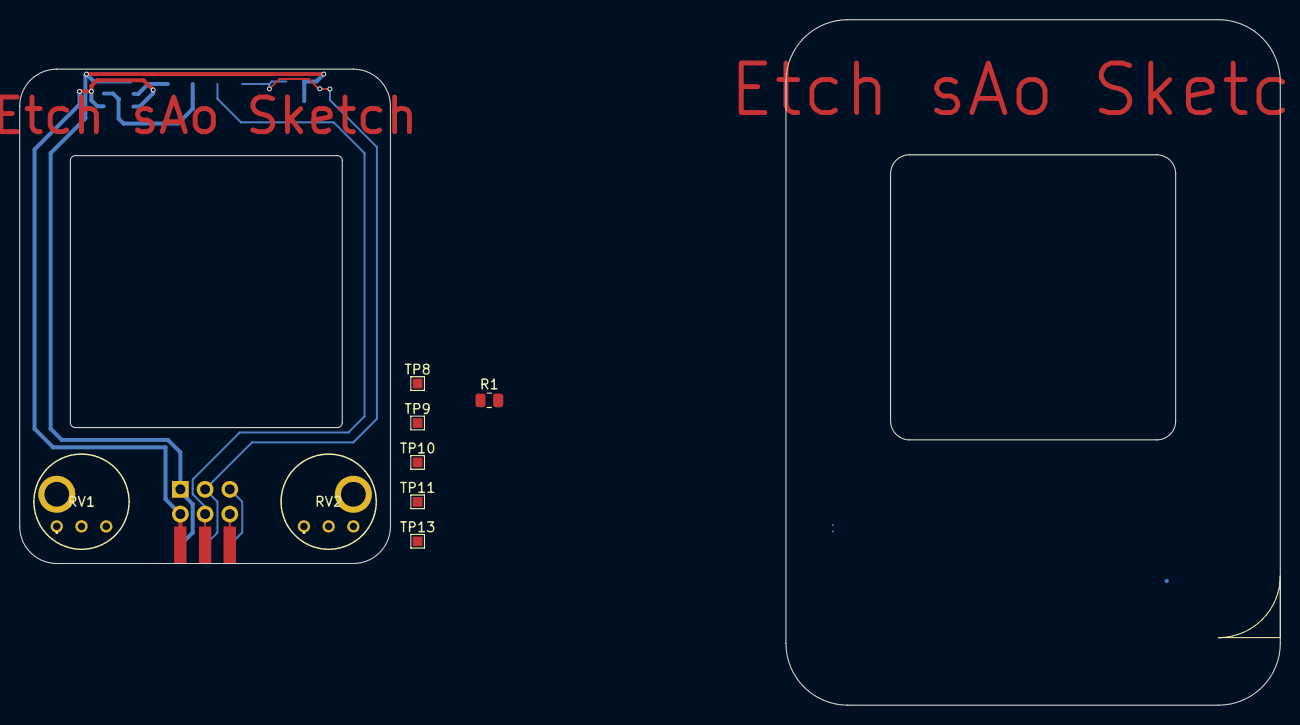
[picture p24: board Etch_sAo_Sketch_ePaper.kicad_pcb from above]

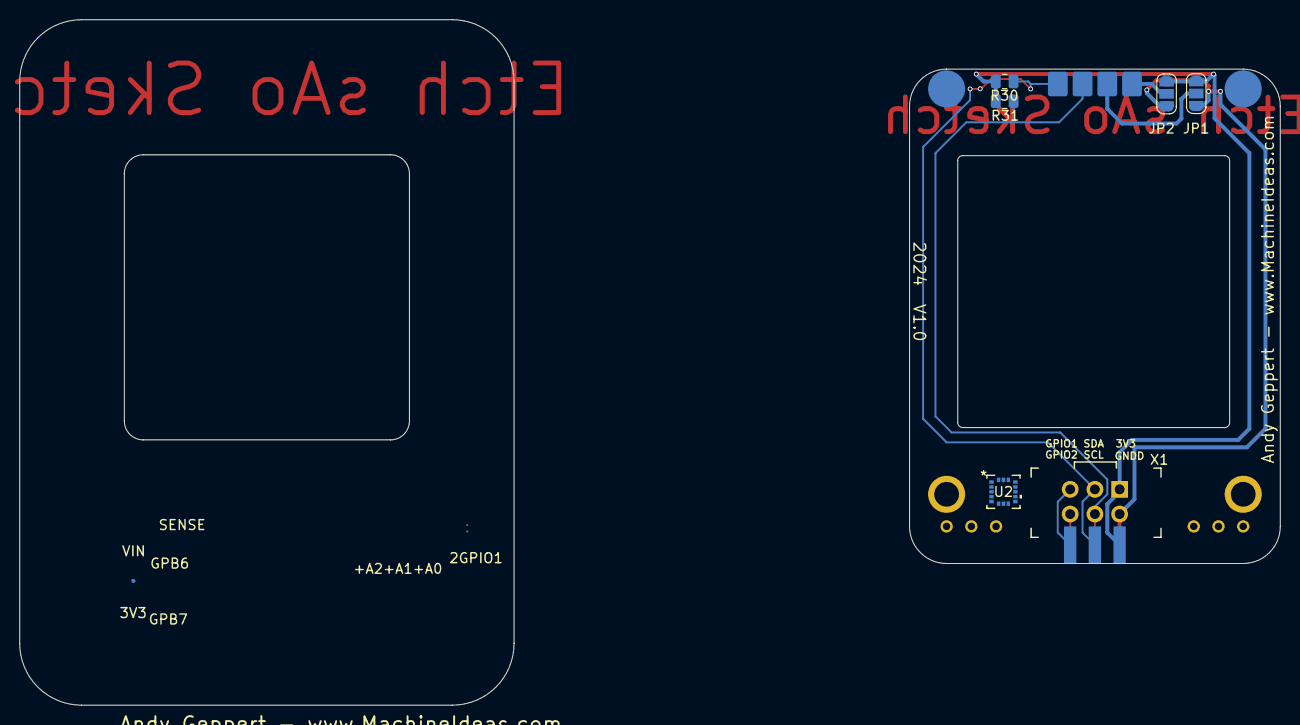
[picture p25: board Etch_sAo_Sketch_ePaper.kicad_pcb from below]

Board: 2 copper layers, 129.5 x 70.4 mm, 15 parts (6 on the bottom side), 14 nets.

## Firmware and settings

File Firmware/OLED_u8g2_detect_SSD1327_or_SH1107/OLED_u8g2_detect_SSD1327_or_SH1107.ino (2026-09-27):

#include <Arduino.h>
#include <Wire.h>
#include <U8g2lib.h>

// 1. Instantiate both possible display structures globally (adjust resolutions/names to match your exact hardware)
U8G2_SSD1327_EA_W128128_F_HW_I2C display_SSD1327(U8G2_R0, /* reset=*/ U8X8_PIN_NONE);
U8G2_SH1107_SEEED_128X128_F_HW_I2C display_SH1107(U8G2_R0, /* reset=*/ U8X8_PIN_NONE);

// 2. Define the generic base object pointer we will use throughout the code
U8G2 *u8g2 = nullptr;

#define DISPLAY_I2C_ADDRESS 0x3C

// bool isSSD1327Connected() {
//   Wire.beginTransmission(DISPLAY_I2C_ADDRESS);
//   // Send a control byte indicating a command stream, followed by an SSD1327-specific command
//   // SSD1327 uses 0x15 for Set Column Address; SH1107 does not have a 0x15 command at top level.
//   Wire.write(0x00); // Co = 0, D/C# = 0 (Command stream)
//   Wire.write(0x15); // Set Column Address command (Unique marker behavior for SSD1327 identification)
  
//   byte error = Wire.endTransmission();
//   return (error == 0); // If 0, the device successfully acknowledged the sequence
// }

bool isSSD1327Connected() {
  // Step 1: Send a status request/command stream token to the display
  Wire.beginTransmission(DISPLAY_I2C_ADDRESS);
  Wire.write(0x00); // Control byte: Co = 0, D/C# = 0 (Command register stream)
  // We send 0x00 which is a NOP (No Operation) or safe command for both chips
  Wire.write(0x00); 
  if (Wire.endTransmission() != 0) {
    return false; // Physical device missing completely
  }

  // Step 2: Request 1 byte back from the display controller's internal status register
  // SH1107 explicitly responds to I2C read requests with its Status Byte.
  // SSD1327 requires a different read routine or returns a static/different bit layout.
  uint8_t readCount = Wire.requestFrom(DISPLAY_I2C_ADDRESS, 1);
  
  if (readCount > 0) {
    uint8_t statusByte = Wire.read();
    Serial.print("Debug - Read Status Byte: 0x");
    Serial.println(statusByte, HEX);

    // On power-up (before .begin() clears or alters states):
    // SH1107 status byte naturally exposes power flags (typically 0x00 or 0x40 depending on panel configurations)
    // We can explicitly look for the SSD1327's unique signature layout.
    // If the read value matches SH1107 default states, assume SH1107.
    
    // A highly reliable fallback is checking a specific bit pattern:
    // SH1107 Bit 6 is 1 when display is ON, 0 when display is OFF. 
    // At boot, the display is OFF, so Bit 6 is 0.
    // If the returned byte is exactly 0x00 or matches SH1107 traits, it's an SH1107.
    if (statusByte == 0x00 || (statusByte & 0x40) == 0) {
      return false; // It's the SH1107
    }
  }

  return true; // Treat as SSD1327 fallback
}

void setup() {
  Serial.begin(115200);
  Wire.begin(); // Boot standard hardware I2C line first
  delay(3000);   // Give the hardware basic stabilization time

  Serial.println("Probing I2C bus for display type...");

  // Verify if a device is active on the expected address at all
  Wire.beginTransmission(DISPLAY_I2C_ADDRESS);
  if (Wire.endTransmission() != 0) {
    Serial.println("Error: No display detected at address 0x3C!");
    while (1); // Halt if completely missing
  }

  //Differentiate between SSD1327 and SH1107
  if (isSSD1327Connected()) {
    Serial.println("Detected: SSD1327 Display. Assigning driver...");
    u8g2 = &display_SSD1327;
  } else {
    Serial.println("Detected: SH1107 Display. Assigning driver...");
    u8g2 = &display_SH1107;
  }

  // 3. Initialize the dynamically assigned driver configuration 
  u8g2->begin();
}

void loop() {
  // 4. Use the generic pointer cleanly everywhere else in your program execution loop
  u8g2->clearBuffer();
  u8g2->setFont(u8g2_font_ncenB14_tr);
  u8g2->drawStr(0, 20, "System Online");
  u8g2->sendBuffer();
  Serial.println("Connected to display.");
  delay(2000);
}

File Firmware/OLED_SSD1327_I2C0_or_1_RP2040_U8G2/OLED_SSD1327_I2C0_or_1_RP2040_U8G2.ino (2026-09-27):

/* 
  RP2040-Zero with SSD1327 on I2C0 or I2C1 with U8g2 Library

  DEPENDENCIES - FIRMWARE
    Install "Arduino Mbed OS RP2040 Boards" v4.2.2 with Arduino Boards Manager
      - The Wire Library is included, I think.
    U8g2lib SSD1327
      https://github.com/olikraus/u8g2/wiki/u8g2setupcpp#reference

  DEPENDENCIES - HARDWARE
    OLED with SSD1327 Driver
    RP2040-Zero

  DESCRIPTION
    1) Test the U8G2 library with the default I2C0 port. Done, works.
    2) Test with I2C1 port... Done. Works!
*/

#include <Arduino.h>
#include <Wire.h>
#include <U8g2lib.h>

// Choose one port
  #define I2C_PORT0 true
  // #define I2C_PORT1 true

#if I2C_PORT0
  #define I2C0_SDA_PIN 4
  #define I2C0_SCL_PIN 5
#endif

#if I2C_PORT1
  #define I2C1_SDA_PIN 2
  #define I2C1_SCL_PIN 3
#endif

/*
  The name of the U8G2 Arduino C++ constructor has the following parts:
  No	Description	        Example
  1	  Prefix	            U8G2
  2	  Display Controller	UC1701
  3	  Display Name	      DOGS102
  4	  Variant (optional)	ALT
  5	  Buffer Size	        1, 2 or F (full frame buffer), see details below
  6	  Communication	      4W_SW_SPI, ...
*/

#if I2C_PORT0
  U8G2_SSD1327_EA_W128128_F_HW_I2C u8g2(U8G2_R0, /* reset=*/ U8X8_PIN_NONE, /* clock=*/ U8X8_PIN_NONE, /* data=*/ U8X8_PIN_NONE);
#endif

#if I2C_PORT1
  U8G2_SSD1327_EA_W128128_F_2ND_HW_I2C u8g2(U8G2_R0, /* reset=*/ U8X8_PIN_NONE);
#endif

void setup() {
  Serial.begin(115200);

  #if I2C_PORT0
    // Set the SDA and SCL pins for the Wire1 object before beginning
    Wire.setSDA(I2C0_SDA_PIN);
    Wire.setSCL(I2C0_SCL_PIN);
    Wire.begin();
  #endif

  #if I2C_PORT1
    // Set the SDA and SCL pins for the Wire1 object before beginning
    Wire1.setSDA(I2C1_SDA_PIN);
    Wire1.setSCL(I2C1_SCL_PIN);
    Wire1.begin();
  #endif

  u8g2.begin();
}

void loop() {
  u8g2.clearBuffer();
  u8g2.setFont(u8g2_font_ncenB14_tr);
  #if I2C_PORT0
    u8g2.drawStr(0, 20, "Hello, I2C0!");
  #endif
  #if I2C_PORT1
    u8g2.drawStr(0, 20, "Hello, I2C1!");
  #endif
  u8g2.sendBuffer();
}

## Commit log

2024-08-25 Remove top SAO port
    [Etch_sAo_Sketch.kicad_pcb, Etch_sAo_Sketch.kicad_sch]
2024-10-13 Add V1 design files, as prototyped
    [Etch_sAo_Sketch.kicad_pcb, Etch_sAo_Sketch.kicad_sch]
2024-10-13 Add images
    [Etch_sAo_Sketch.step]
2024-10-13 Add V1 manufacturing files
    [Etch sAo Sketch V1.0 2024-09-27 BOM.xlsx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]
2024-10-28 Add schematic for V1 OLED
    [Etch_sAo_Sketch.kicad_sch]
2024-10-28 Update schematic filename, remove older schematic
2024-11-15 Add cap STL for potentiometer thumbwheels
    [Etch sAo Sketch Pot Cap V1.stl]
2024-11-16 Add mechanical parts source CAD link, STEP, IGES, parasolid, Solidworks versions
    [Etch sAo Sketch Pot Cap V1.iges, Etch sAo Sketch Pot Cap V1.sldprt, Etch sAo Sketch Pot Cap V1.step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]
2024-11-19 Add V1.1 design files
    [Etch sAo Sketch V1.1 2024-11-18 BOM.xlsx, Etch_sAo_Sketch.kicad_pcb, Etch_sAo_Sketch.kicad_sch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]
2024-11-19 Update schematic notes V1.1, add manufacturing verification images
    [Etch_sAo_Sketch.kicad_sch]
2024-11-22 Create Etch sAo Sketch V1.1 2024-11-21 BOM Complete.xlsx
    [Etch sAo Sketch V1.1 2024-11-21 BOM Complete.xlsx]
2024-11-22 Improved V1.1 BOM
    [Etch sAo Sketch V1.1 2024-11-21 BOM Complete.xlsx, Etch sAo Sketch V1.1 2024-11-22 BOM Complete.xlsx]
2024-12-01 Hardware V1.1 schematic and firmware test updated
    [Etch_sAo_Sketch.kicad_sch, Resistor range calcs.xlsx]
2024-12-02 Hardware 1.2 increase pot solder pad diameter
    [Etch_sAo_Sketch.kicad_pcb, Etch_sAo_Sketch.kicad_sch]
2024-12-12 Move V1.2 files to a new repository, update README
    [Etch_sAo_Sketch.kicad_pcb, Etch_sAo_Sketch.kicad_sch]
2025-03-15 Working micropython MVP implementation
    - Swap from HW i2c to SW i2c on i2c1
    - Swap out the ssd1327 library with this one: https://github.com/mcauser/micropython-ssd1327/tree/master
    - Draw lines instead of pixels
    - Implement a potentiometer calibration routine (not working right now it seems)
    [boot.py, etch_sao_sketch.py, lis3dh.py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]
2025-03-15 Improve calibration routine
    Add instructions on OLED screen for how to calibrate potentiometers.
    (I forgot that I had already fixed the calibration routine in my previous commit, lol)
    [etch_sao_sketch.py, main.py]
2025-03-15 Add line in README about accelerometer
    Add line in README about half-finished accelerometer implementation
2025-03-16 Enable shaking to clear the screen
    Accelerometer implementation inspired by https://github.com/bastlirna/hackaday2025_badge/tree/main
2025-03-17 Fix accelerometer implementation
    - Fix i2c communication issue towards lis3dh by adding small delay after changing data_rate
    - Increase accelerometer range from 2G to 8G and tune sensitivity
    - Remove 20ms delay in main loop. This makes the drawing more responsive, but also more noisy.
    - Remove a few unnecessary prints and comments
    [boot.py, etch_sao_sketch.py, lis3dh.py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]
2025-03-18 Fix crash, Bendy compatibility
    - Fix crash when Etch sAo Sketch is not connected to the badge
    - Set all GPIOs to input mode for compatibility with Etch sAo Sketch and
    Bendy, so they can be plugged in any port on the badge
    Note: Setting GPIO to Input mode will set it to 0.8V instead of 0V
    This is required to not prevent Bendy from booting
    See https://github.com/bastlirna/hackaday2025_bsao_addon/blob/main/Readme.md
    [boot.py, etch_sao_sketch.py, main.py]
2025-03-22 tried "shake" from lis3dh, but reverted back to "tapped" due to time consumed - left a comment
    [etch_sao_sketch.py, lis3dh_wrapper.py]
2025-03-22 added missing display-exists check to the draw_display()
    [etch_sao_sketch.py]
2025-03-24 Experimenting Arduino sketch to test OLED
2025-03-24 Add work-in-progress ePaper version.
    Needs a lot more work and a refresh from the latest OLED version to catch up with all the analog circuit changes. This project is on the back-burner right now.
    [Etch_sAo_Sketch_ePaper.kicad_pcb, Etch_sAo_Sketch_ePaper.kicad_sch]
2025-03-24 Add V1.3 OLED Hackaday Europe 2025 version design files
    [SAO Sketch V1.2 2024-11-18 BOM JLCPCB.xlsx, SAO Sketch V1.2 2024-12-11 BOM Elecrow.xlsx, SAO Sketch V1.2 2024-12-11 BOM Supplyframe.xlsx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]
2025-04-01 Add I2C pull-up errata notes and SAO_Sketch_V1.3 Schematic Errata 2025-04-01.pdf
    Too much combined I2C pull-up resistance!
    [SAO_Sketch.kicad_sch]
2025-04-18 Create Etch sAo Sketch DIY box cut sticker 2x4.xlsx
    [Etch sAo Sketch DIY box cut sticker 2x4.xlsx]
2025-04-18 Name schematics and electronic design consistently
    [SAO_Sketch.kicad_pcb, SAO_Sketch.kicad_sch]
2025-04-18 Begin OLED V1.4 design, WIP
    [SAO_Sketch.kicad_pcb, SAO_Sketch.kicad_sch]
2025-04-18 Clean-up Arduino Demo Code and comments V1.3
2025-04-19 Fix erase screen and other enhancements.
    Fix and improve shake side-to-side (upside down or right side up) to erase.
    Disable screen inversion and pot input select gestures.
    Add LOAD and RUN, and display firmware/hardware versions.
    [Etch_sAo_Sketch_RP2040_W_Arduino_Demo.ino]
2025-04-25 Add V2 knob STL
    Should have a slightly improved fit.
    [Etch sAo Sketch Pot Cap V2.stl]
2025-04-25 Add version notes where I already removed un-needed pull-up resistors before shipping.
2025-04-26 FWV1.3.2: Fix glitching wrap-around at ends by bounding ADC count reading with HWV1.3.
    [Etch_sAo_Sketch_RP2040_Demo.ino]
2025-04-26 FWV1.3.3 : Tighten ADC left/bottom range to ensure drawing to edges of screen with HWV1.1+.
    Include pre-built demo code to tag for release!
    [Etch_sAo_Sketch_RP2040_Demo.ino]
2025-08-14 Remove stickers folder
    [Etch sAo Sketch DIY box cut sticker 2x4.xlsx]
2025-08-16 Quicker boot up, red LED breathing.
2025-08-19 FWV1.3.5: Adjusted low end voltage/ADC to work with 3.0V supply, accounting for Demo Controller V2 diode drop.
2025-10-01 Add support to optionally connect Etch sAo Sketch to the incoming SAO port I2C1 to fully cover the Demo Controller.
    Includes demo code to use second I2C1 port with alternate U8G2 OLED SSD1327 library.
2026-09-27 Add OLED 1.5 data sheets, add mechanical parts.
    [Etch sAo Sketch Case Main V1.stl, Etch sAo Sketch Case Plug V1.stl, Etch sAo Sketch Pot Cap V4.stl]
2026-09-27 Add V1.4.0 hardware design
    [SAO_Sketch.kicad_pcb, SAO_Sketch.kicad_sch]
2026-09-27 Remove old manufacturing files
    [Etch sAo Sketch V1.0 2024-09-27 BOM.xlsx, Etch sAo Sketch V1.1 2024-11-18 BOM.xlsx, Etch sAo Sketch V1.1 2024-11-22 BOM Complete.xlsx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]
